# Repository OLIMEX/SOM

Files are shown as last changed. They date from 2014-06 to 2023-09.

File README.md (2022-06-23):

=System on Module=

This is the GitHub repository for Olimex System on Module (SOM) boards resources hardware and software.

OLIMEX System-on-Module (SOM) boards are powerful Linux-capable boards. They follow a low-cost modular design which allows rapid product development. Each of these boards has two parts - a main part which nests the processor, the memory and the power control unit; and a peripheral part which contains the USB ports, the video output and most of the connectors. SOM designs are targeted at customers who want to apply custom modifications and own solutions based on a specific processor without having to deal with multi layer PCBs with controlled impedance and BGA assembly. This makes it possible to create simpler boards (that might be manufactured by your local board manufacturer) containing only the peripherals you need with the dimensions and shape suitable for your specific solution.

Both the main part and the peripheral part of the SOM system have support in the official Android and Debian images distributed by Olimex and maintained by Olimex and the Linux community.

The peripheral part of the SOM design is considered Open Source HardWare (OSHW) and the customer has access to the board source files that we used to manufacture it. The part of the design that has the main microcontroller is considered proprietary design and design files would not be shared. The official Android and Debian images released for the SOM boards are open software. We usually try to provide step-by-step instructions on how we have compiled the images. These instructions might be found at the olimex wordpress page. 

If you are looking for the open source hardware design of the processors used, please, check the OLinuXino boards. OLinuXino board designs are fully open source hradware but harder to implement in own solutions and require more of a hardware experience to do so. Nevertheless OLinuXino boards are pretty good choice for evaluating the capabilities of the embedded processors.

At the moment Olimex deals with the following categories of SOM boards:

==Allwinner A13==

==Allwinner A20==

==Texas Instruments AM3352==

==Rockchip RK3188==

==Rockchip RK3328==

==STM STM32MP153==

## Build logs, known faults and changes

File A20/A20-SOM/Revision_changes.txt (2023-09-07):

Notable hardware changes in A20-SOM's design betwen revisions

Hardware revision C
========

1. Added resistor 10M parallel to the RTC crystal.
2. Changed the RTC crystal to SMT package.
3. Edited web-site white print to https://www.olimex.com
4. D5 positioned further away from UART0 conectora.
5. Major canges to the routing of DDR3 and NAND memory, similar to LIME2's. 
6. Instead of test pads, added new connector with the following signals:
	-> FMINL, FMINR, TVIN2, TVIN3, VMIC_OUT, AXP_BACKUP, AXP_RST, AXP_PWRON, UBOOT_SEL, VDD_RTC and GND;
7. Added new option - PC17 could be used for NWP signal if necessary, but R22 should be placed in this case!

Hardware revision D
========

1. Added matrix RM3 for the VGA signals.
2. Added pads for optional capacitors C178, C179, C180, C181 (NA by default).
3. VDD_RTC's label fixed from 3V3/30mA to 1V3/30mA.

Hardware revision E
========

1. Added AT24C16C EEPROM on TWI1 line. EEPROM address 0x50. Can cause problems with devices that use I2C1 since it blocks
addresses 0x50 to 0x57. The EEPROM comes loaded with production information, refer to this repo for more information:
https://github.com/OLIMEX/OLINUXINO/tree/master/SOFTWARE/A20/A20-eeprom-contents
2. Added eMMC option.
3. Added SPI flash option.
4. C162(220uF/6.3V/tant) changed to 4x47uF/6.3V/0805.
5. U2 and U3 changed from K4B4G1646D-BCK0 to MT41K256M16HA-125E(DDR3L-1600_11-11-11).
6. Added 5 x R22 resistors on ETX lines to reduce Ethernet noise.

Hardware revision E1
=========

1. C193 and L9 pads added for ETXCK and components not placed (NA).
2. Added option to make the board with T2 chip instead of A20.
3. Change RTC crystal with 1206 one.

Hardware revision E2
=========
Improved a lot of capacitors near the AXP209, so that they match the recommendations better:

1. C141 10uf/0603 --> 1uF/0603
2. C145 10uF/0603 --> 4.7uF/0603
3. C147 10uF/0603 --> 4.7uF/0603
4. C148 10uF/0603 --> 4.7uF/0603
5. C150 10uF/0603 --> 4.7uF/0603
6. C123 10uF/0603 --> 4.7uF/0603
7. C128 10uF/0603 --> 4.7uF/0603
8. C134 1uF/0603 --> 4.7uF/0603
9. C144 10uF/0603 --> 220nF/0603
10. 2.2uH/1.5A/DCR<0.1R/CD32 now 2.2uH/NR3015T2R2M/1.5A/3015
11. MCP120T475I-TT is now MCP121T475I-TT
12. Q32.768kHz/12.5pF/20ppm/4P/SMD8038 is now Q32.768kHz/12.5pF/2P/SMD1206

Hardware revision E3
=========
1. eMMC KLMAG2GEND-B031(FBGA153)(16G) changed with KLMAG1JETD-B041(FBGA153)(16G)
2. RAM changed to Samsung K4B4G1646D-BYK0 from Micron MT41K256M16HA-125E

Hardware revision E4
=======
1. Changed RAM used from Micron MT41K256M16HA-125E to Samsung K4B4G1646D-BYK0

Hardware revision F
=======

1. R86 and R72 connected to EFUSE_VDDQ.
2. Replaced U6 (MCP121T475I-TT) with U19(VDA4510CTA). U19(VDA4510CTA) was placed in parallel to U6(MCP121T475I-TT) and U6 was made NA. 
3. Added "CE" sign and "RoHS Compliant" text.
4. At some point 8GB eMMC(MTFC8GAKAJCN-4M IT) become unavable for purchase and the only repalcement avialable was 16GB industrial eMMC(KLMAG2GEUF-B04P). We decided to replace all 8GB eMMC with 16GB eMMC.

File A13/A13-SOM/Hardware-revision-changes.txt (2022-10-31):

Notable hardware changes for A13-SOM boards. 

In hardware revision Rev_E2
========
1. Changed RAM memory. New memory might have poor support in sunxi kernel u-boot; mainline u-boot should be used in case of issues.

In hardware revision Rev_F
========
1. C81 changed from 100uF/6.3V/tant/CT7343 to 2 x capacitors in parallel each 47uF/6.3V/20%/X5R/C0805;
2. L3 now 0R(board_mounted) resistor;
3. Package improvements of several components for better soldering;
4. Board size increased from 1300x2400mils to 1350x2400mils. Each side was increased with 25mils. This was done due to complaints about the reliability of the plastic headers. They should be more reliable now.

In hardware revision Rev_G
========
1. The packages of most resistor matrices improved;
2. C67 and C76 changed from 22pF to 33pF;
3. L1 changed from CL470nH/0805/1.76R/250mA to FB0805/600R/2A;
4. In A13-SOM256: R7 and R9 changed from 330 Ohm to 240 Ohm

In hardware revision Rev_G1
=========
1. RAM memory changed to K4B4G1646D-BYK0.
2. SY8009 changed with SY8089. 
3. 2.2uH (L2 and L4) now 2.2uH/NR3015T2R2M/1.5A/3015.
4. Changed R13 from 2k/1%/0603 to 2.2k/1%/0603, this is done to increase
the voltage on the processor to around 1.45V.

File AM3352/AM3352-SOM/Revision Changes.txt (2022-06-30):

AM3352-SOM notable hardawre revision changes

Hardware revision C1
===
1. R46 value changed from 10k to 1k.

Hardware revision D
===
1. NAND_RPR jumper was added to avoid the problem with booting when the NAND is broken;
2. All SY8009AAAC changed to SY8089AAAC.

Hardware revision E
===
1. Q1 changed from 32768Hz/6pF/4P to Q32.768kHz/12.5pF/2P/SMD1206;
2. C89 and C91 changed from 10pF to 22pF;
3. The drills under C100 were moved a little bit away from the pads. So L3 was moved 5mils to the right;
4. NAND_RPR jumper replaced with the R66(NA(10k)) resistor. In addition, R65(NA(10k)) and R67-R69(NA(10k)) added to support different boot orders, as written in the schematic, if required.
5. L4, L5, L7 and L8 changed from 2.2uH/1.5A/DCR<0.1R/CD32 to 2.2uH/1.5A/DCR=72mR/20%/3.00x3.00x1.50mm/CD32(NR3015T2R2M);
6. L6 changed from CL470nH/0805/1.76R/250mA to FB0805/600R/2A;
7. D1's value changed from 1N4148 to 1N4148W(SOD-123);
8. The board enlarged with 10mils around for to avoid having drills and wires close to the board's edge;
9. When there is no NAND there is no need to populate c106 and r28.

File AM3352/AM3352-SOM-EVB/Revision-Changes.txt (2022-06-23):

Hardware revision changes AM3352-SOM-EVB:

In revision E
====
1. Q1's package changed from 32768Hz/6pF/4P to Q32.768kHz/12.5pF/2P/SMD1206;
2. C89 and C91 values changed from 10pF to 22pF;
3. The drills under C100 were moved a little bit away from the pads. For this purpose L3 was moved 5mils to the right;
4. NAND_RPR jumper replaced by the R66(NA(10k))resistor. In addition, R65(NA(10k))and R67-R69(NA(10k)) added to support different boot order, as written in the schematic, if required.
5. L4,L5,L7 and L8 changed from 2.2uH/1.5A/DCR<0.1R/CD32 to 2.2uH/1.5A/DCR=72mR/20%/3.00x3.00x1.50mm/CD32(NR3015T2R2M);
6. L6 changed from CL470nH/0805/1.76R/250mA to FB0805/600R/2A;
7. D1's value changed from 1N4148 to 1N4148W(SOD-123);
8. The board enlarged with 10 mils around to avoid having drills and wires close to the board's edge;
9. When there is no NAND, we don't populate c106 and r28.

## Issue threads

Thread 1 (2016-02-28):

PCB design files for A13-SOM

AlexDaniel, 2016-02-28:
I can only see schematics here: https://github.com/OLIMEX/SOM/tree/master/A13/A13-SOM
What about .brd files?

DanKoloff, 2016-02-29:
Hey there,

The SOM boards designed and manufactured by Olimex LTD are not open-source hardware. If you look at the web-pages of A13-SOM, A20-SOM, RK3188-SOM, etc/ you would notice that they don't have the OSHW logo. Only the reference shields for these boards are open-souce hardware (like A13-SOM-WIFI, A20-SOM-EVB, etc).

This is described in the documentation. More information can also be found here: [https://www.olimex.com/Products/SOM/](https://www.olimex.com/Products/SOM/)

If you are looking for OSHW design with Allwinner A13 - take a look at OLinuXino and LIME boards. For example, A13-OLinuXino and A13-OLinuXino-MICRO are OSWH boards.

Best regards,
Lub/OLIMEX

Closed 2016-02-29.

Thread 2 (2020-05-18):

datasheet of RK3188

iysheng, 2020-05-18:
Hi，thanks for your work，and i want design a board based on your RK3188-SOM,I can get your schematics, could you provide the datasheet or usermanual of RK3188,i google some thing but no get the right doc.

TsvetanUsunov, 2020-05-18:
you didn't search hard enough https://github.com/OLIMEX/OLINUXINO/tree/master/DOCUMENTS/RK3188-PDFs

iysheng, 2020-05-18:
>
>
> you didn't search hard enough https://github.com/OLIMEX/OLINUXINO/tree/master/DOCUMENTS/RK3188-PDFs

e, thanks for your reply,

Closed 2020-05-18.

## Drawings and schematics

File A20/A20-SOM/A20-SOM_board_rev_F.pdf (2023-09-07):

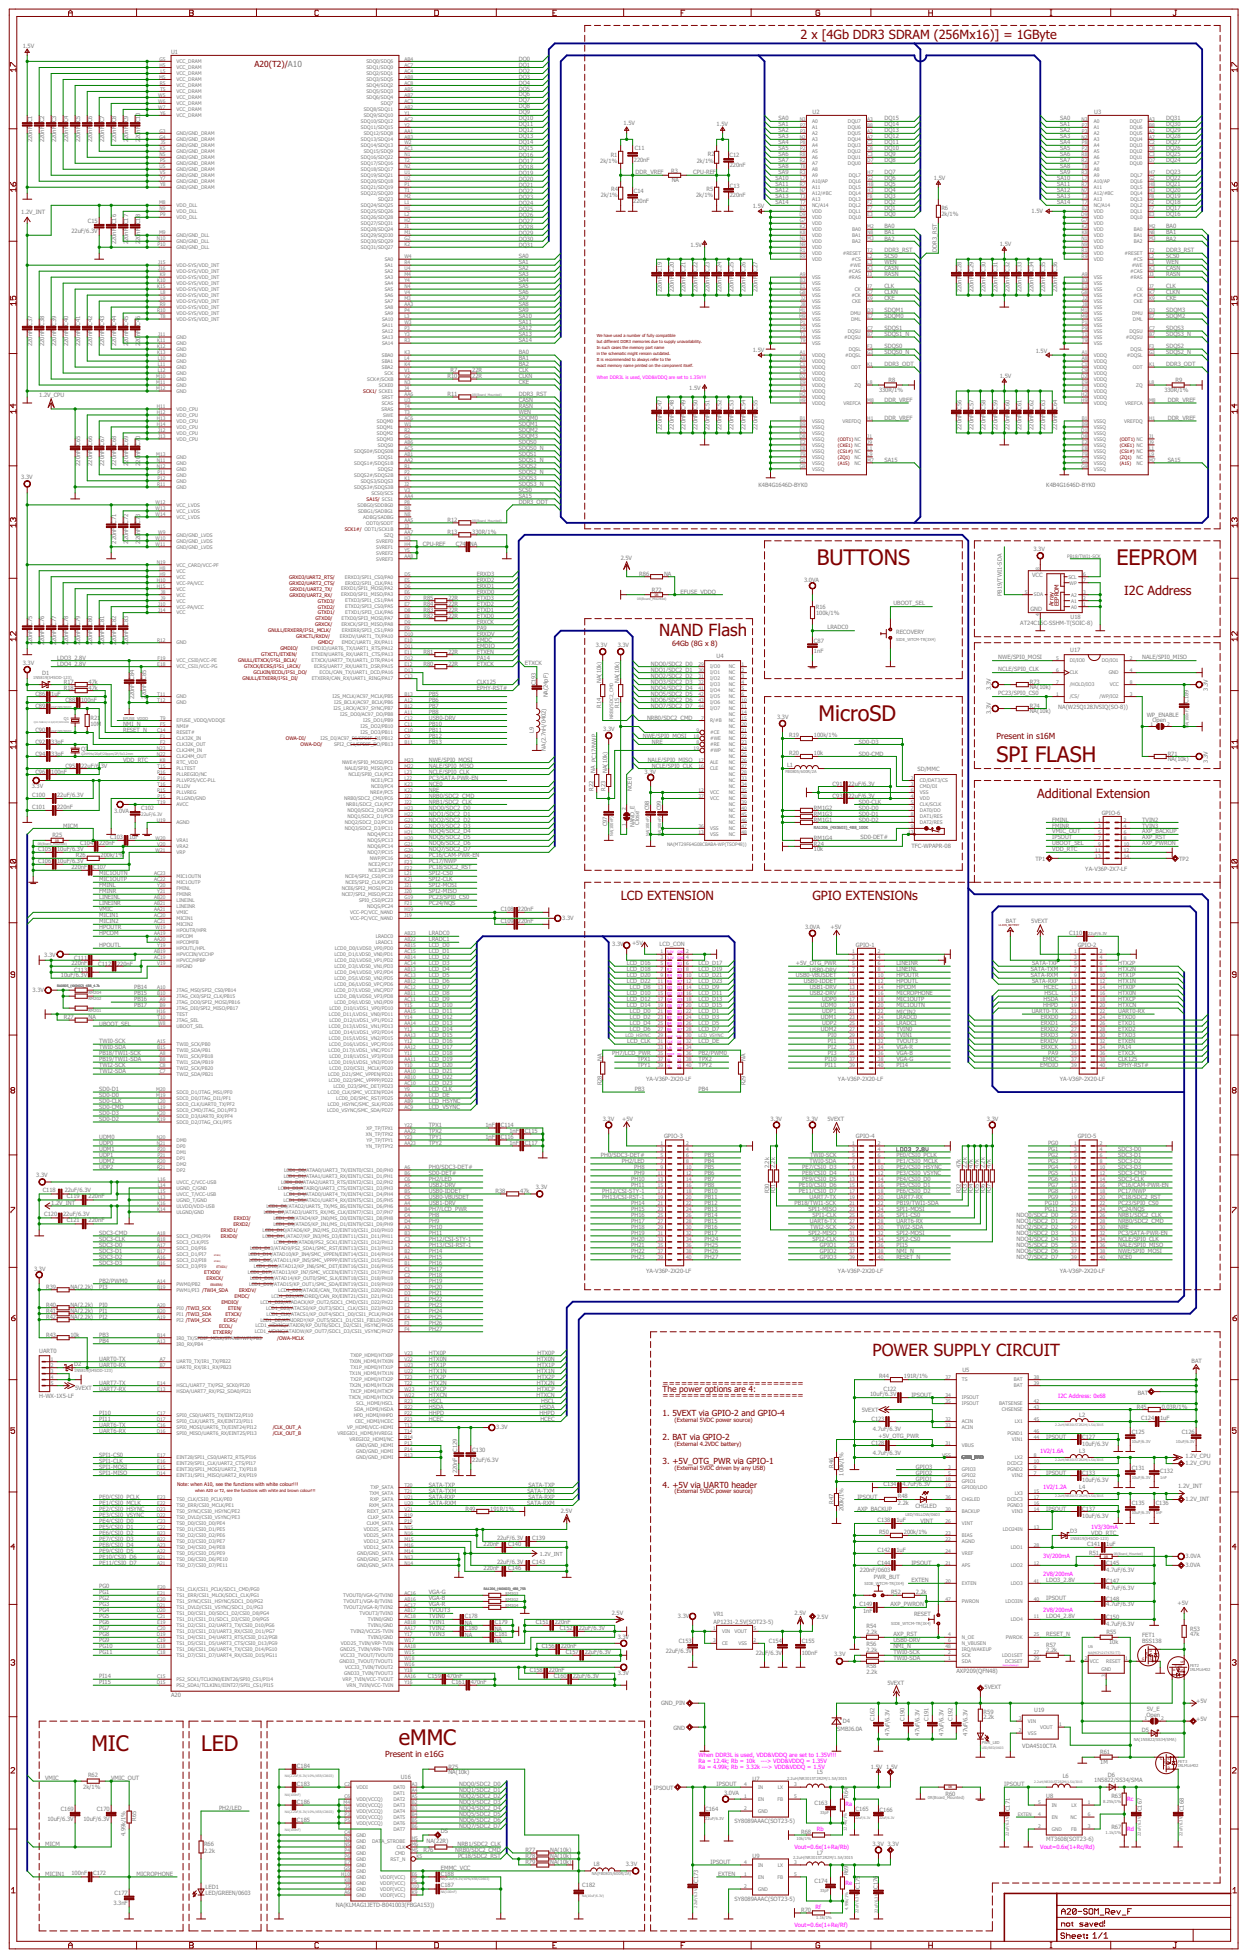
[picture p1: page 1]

We have used a number of fully compatible but different DDR3 memories due to supply unavailability. In such cases the memory part name

in the schematic might remain outdated. It is recommended to always refer to the

exact memory name printed on the component itself.

When DDR3L is used, VDD&VDDQ are set to 1.35V!!!

GRXD3/UART2_RTS/ GRXD2/UART2_CTS/ GRXD1/UART2_TX/ GRXD0/UART2_RX/ GTXD3/ GTXD2/ GTXD1/ GTXD0/ GRXCK/ GNULL/ERXERR/I²S1_MCLK/ GRXCTL/RXDV/ GMDC/ GMDIO/ GTXCTL/ETXEN/ GNULL/ETXCK/I²S1_BCLK/ GTXCK/ECRS/I²S1_LRCK/ GCLKIN/ECOL/I²S1_DO/ GNULL/ETXERR/I²S1_DI/

OWA-DI/ OWA-DO/

The power options are 4: 1. 5VEXT via GPIO-2 and GPIO-4

3. +5V_OTG_PWR via GPIO-1
(External 5VDC driven by any USB)

Note: when A10, see the functions with white colour!!! when A20 or T2, see the functions with white and brown colour!!!

When DDR3L is used, VDD&VDDQ are set to 1.35V!!! Ra = 12.4k; Rb = 10k ---> VDD&VDDQ = 1.35V Ra = 4.99k; Rb = 3.32k ---> VDD&VDDQ = 1.5V

RcRd Vout=0.6x(1+Rc/Rd) Re Rf Vout=0.6x(1+Re/Rf)

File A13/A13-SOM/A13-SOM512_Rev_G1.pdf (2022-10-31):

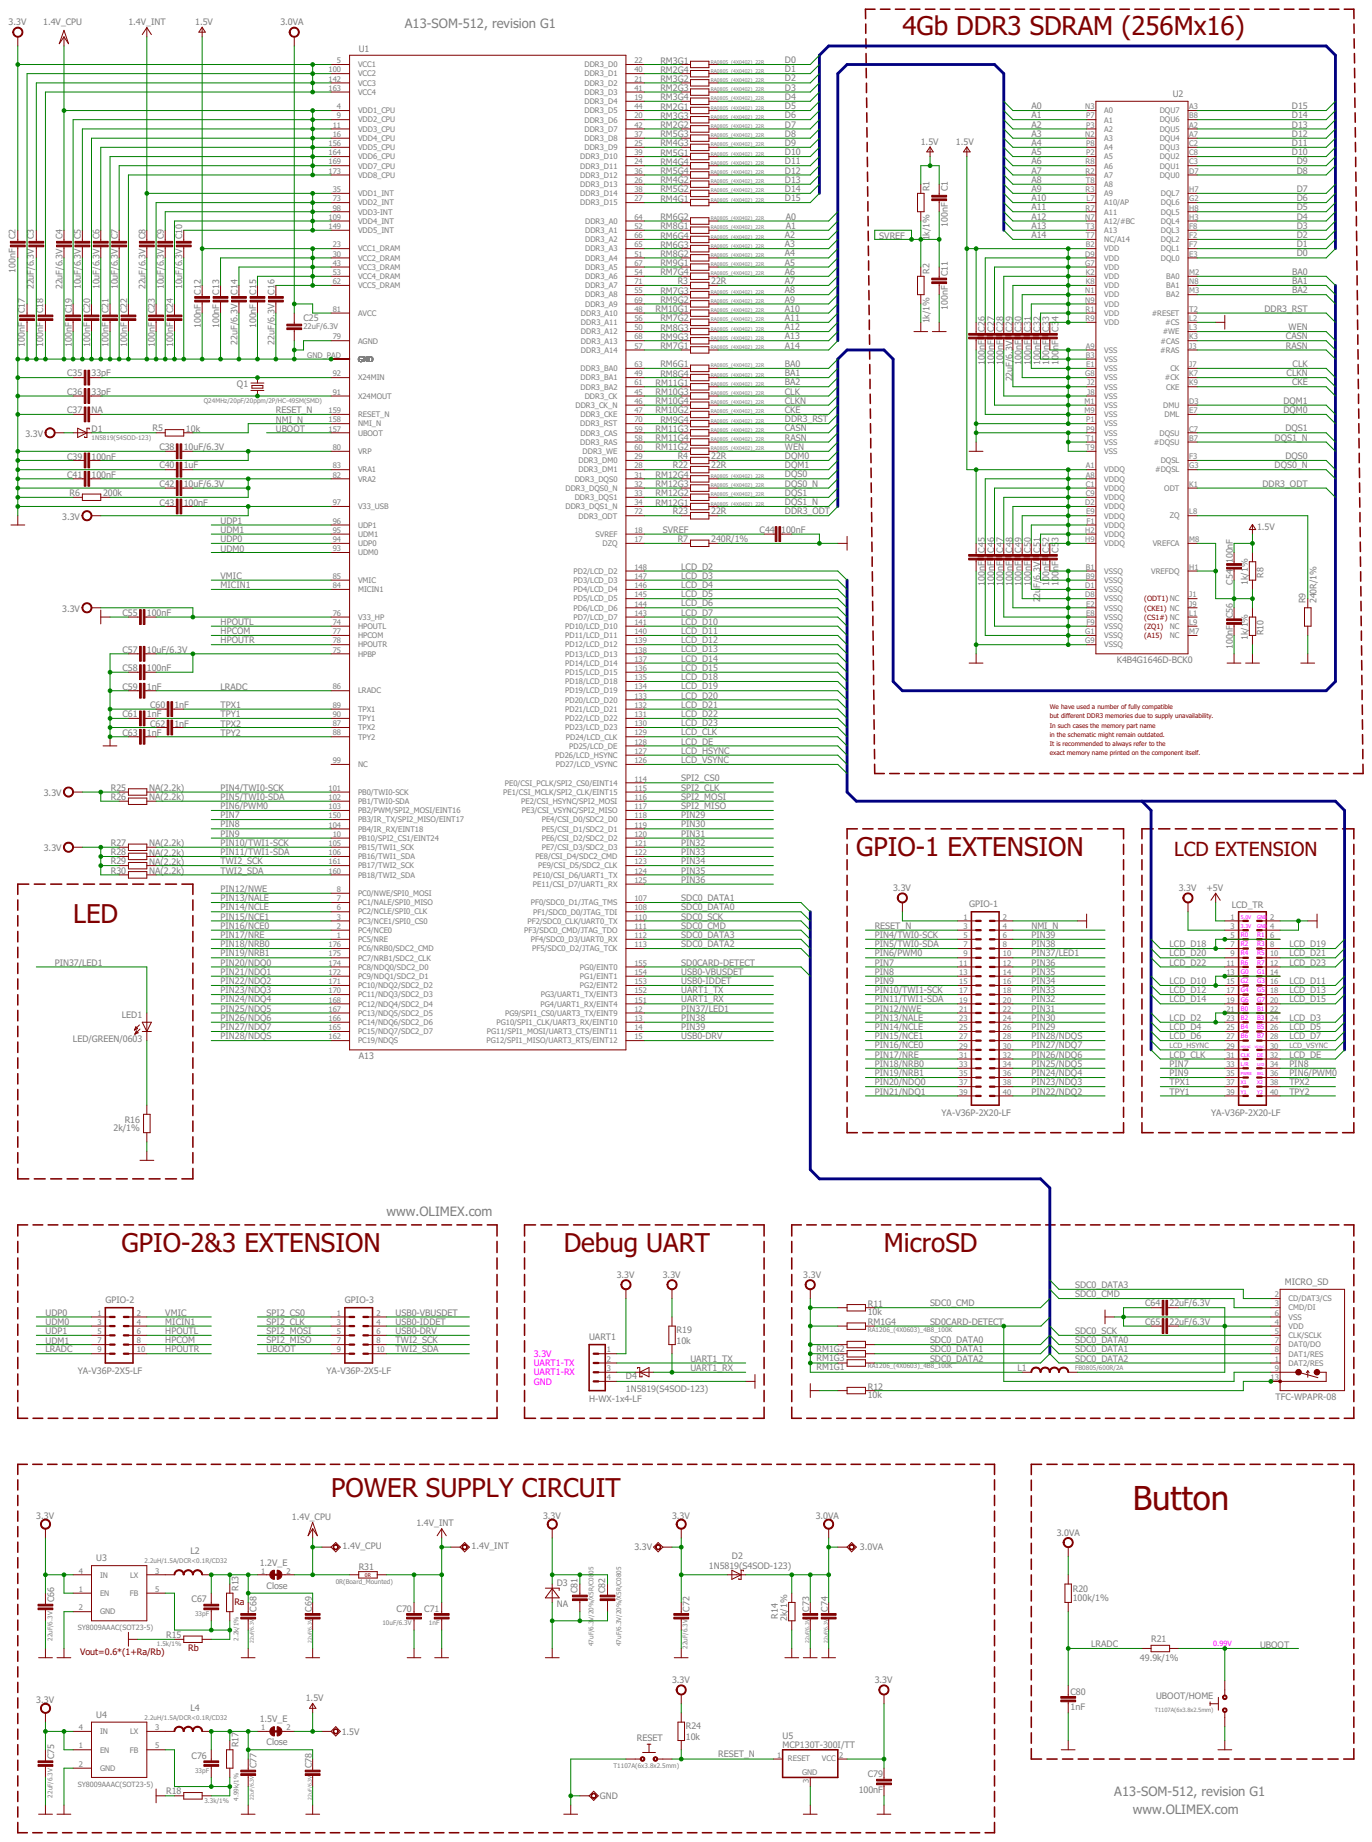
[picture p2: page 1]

142 | RM2G1 RM2G2 RM2G3 RM2G4 RM3G1 RM3G2 RM3G3 RM3G4 40 DDR3_D3
100 | 21 DDR3_D0

4 | 20 DDR3_D2 41 DDR3_D7
163

30
81 | RM9G1 RM9G2 RM9G3
62 | 54 DDR3_A8 71 R3

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

in the schematic might remain outdated. It is recommended to always refer to the

exact memory name printed on the component itself.

Ra Rb Vout=0.6*(1+Ra/Rb)

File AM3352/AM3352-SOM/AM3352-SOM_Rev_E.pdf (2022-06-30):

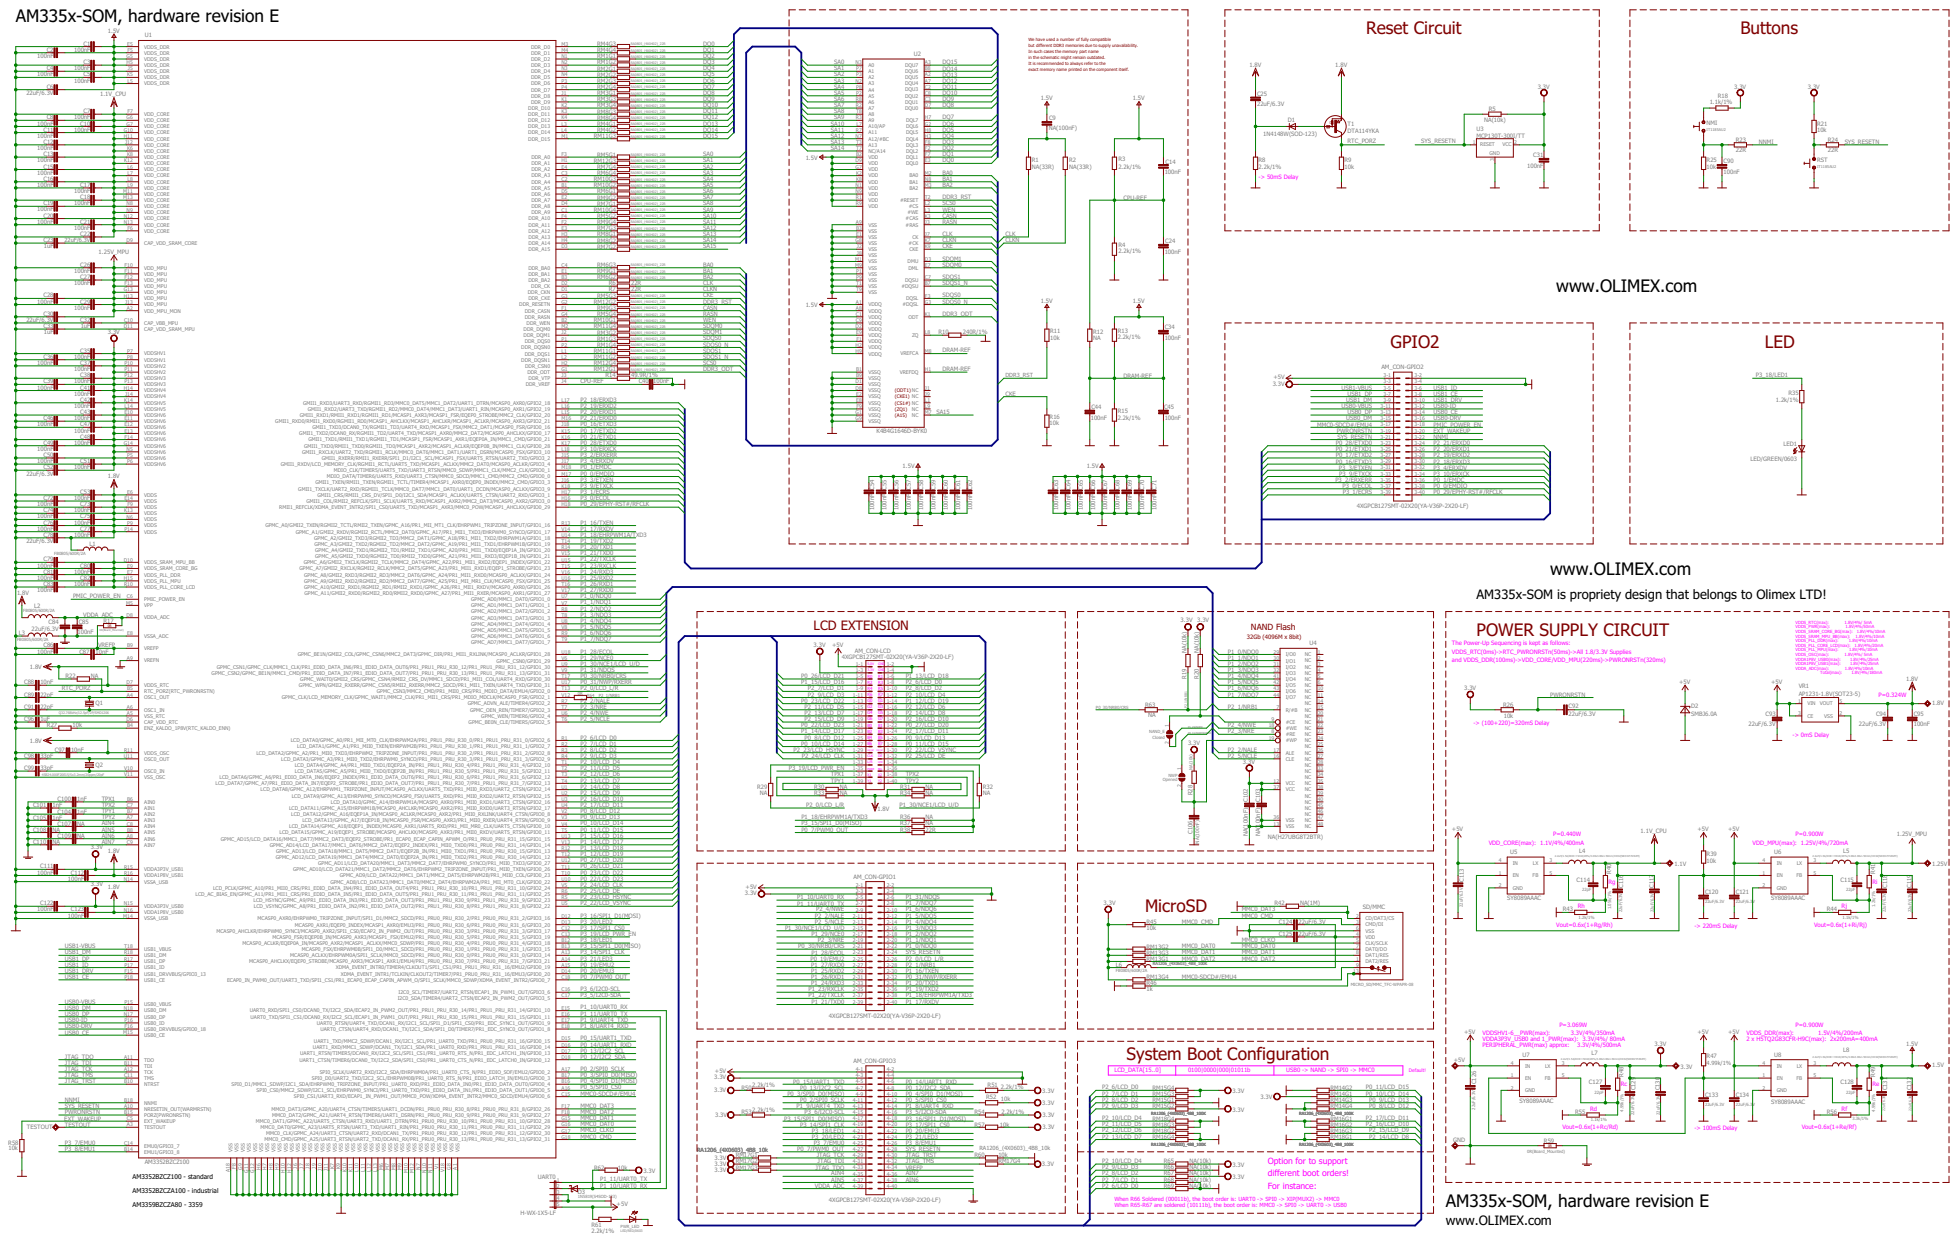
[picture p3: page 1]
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

in the schematic might remain outdated. It is recommended to always refer to the

exact memory name printed on the component itself.

DRAM-REF DRAM-REF DRAM-REF

AM335x-SOM is propriety design that belongs to Olimex LTD!

The Power-Up Sequencing is kept as follows: VDDS_RTC(0ms)->RTC_PWRONRSTn(50ms)->All 1.8/3.3V Supplies and VDDS_DDR(100ms)->VDD_CORE/VDD_MPU(220ms)->PWRONRSTn(320ms)

Rg Rh Vout=0.6x(1+Rg/Rh)

Ri Rj Vout=0.6x(1+Ri/Rj)

Rc Rd Vout=0.6x(1+Rc/Rd)

Re Rf Vout=0.6x(1+Re/Rf)

When R66 Soldered (00011b), the boot order is: UART0 -> SPI0 -> XIP(MUX2) -> MMC0 When R65-R67 are soldered (10111b), the boot order is: MMC0 -> SPI0 -> UART0 -> USB0

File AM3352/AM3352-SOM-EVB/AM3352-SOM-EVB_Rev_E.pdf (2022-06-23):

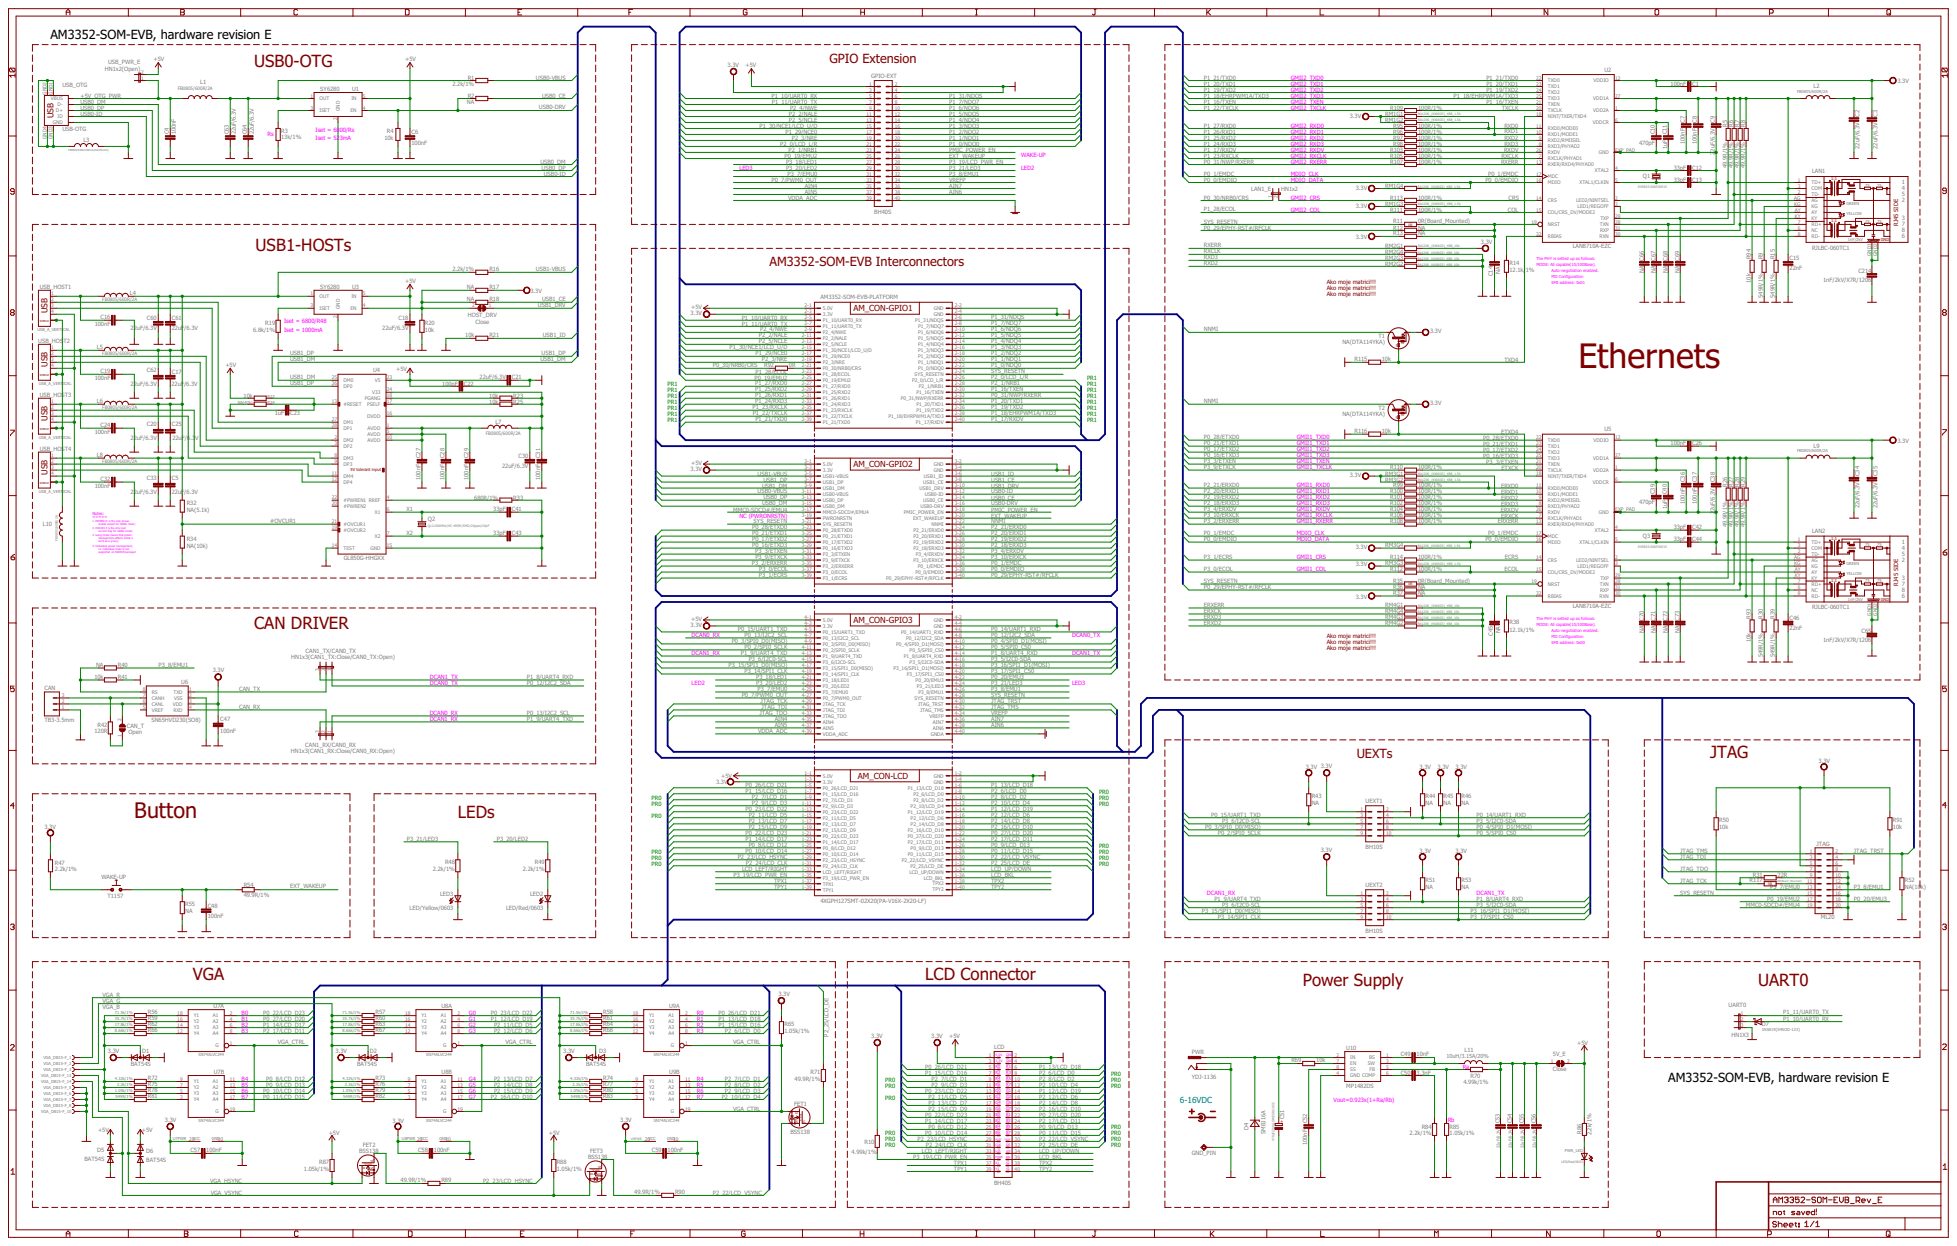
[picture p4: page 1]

AM3352-SOM-EVB, hardware revision E

The PHY is setted up as follows: MODE: All capable(10/100Base). Auto-negotiation enabled. MII Configuration

Ako moje matrici!!! Ako moje matrici!!! Ako moje matrici!!!

enable output for GANG mode; 1. PWREN1# is the only power- Notes:

current flag for GANG mode; 2. OVCUR1# is the only over ports as a group; 3. Gang mode means that power 4. Individual power management,

i.e. individual mode is not supported on SSOP28 package!

Rb Vout=0.923x(1+Ra/Rb)

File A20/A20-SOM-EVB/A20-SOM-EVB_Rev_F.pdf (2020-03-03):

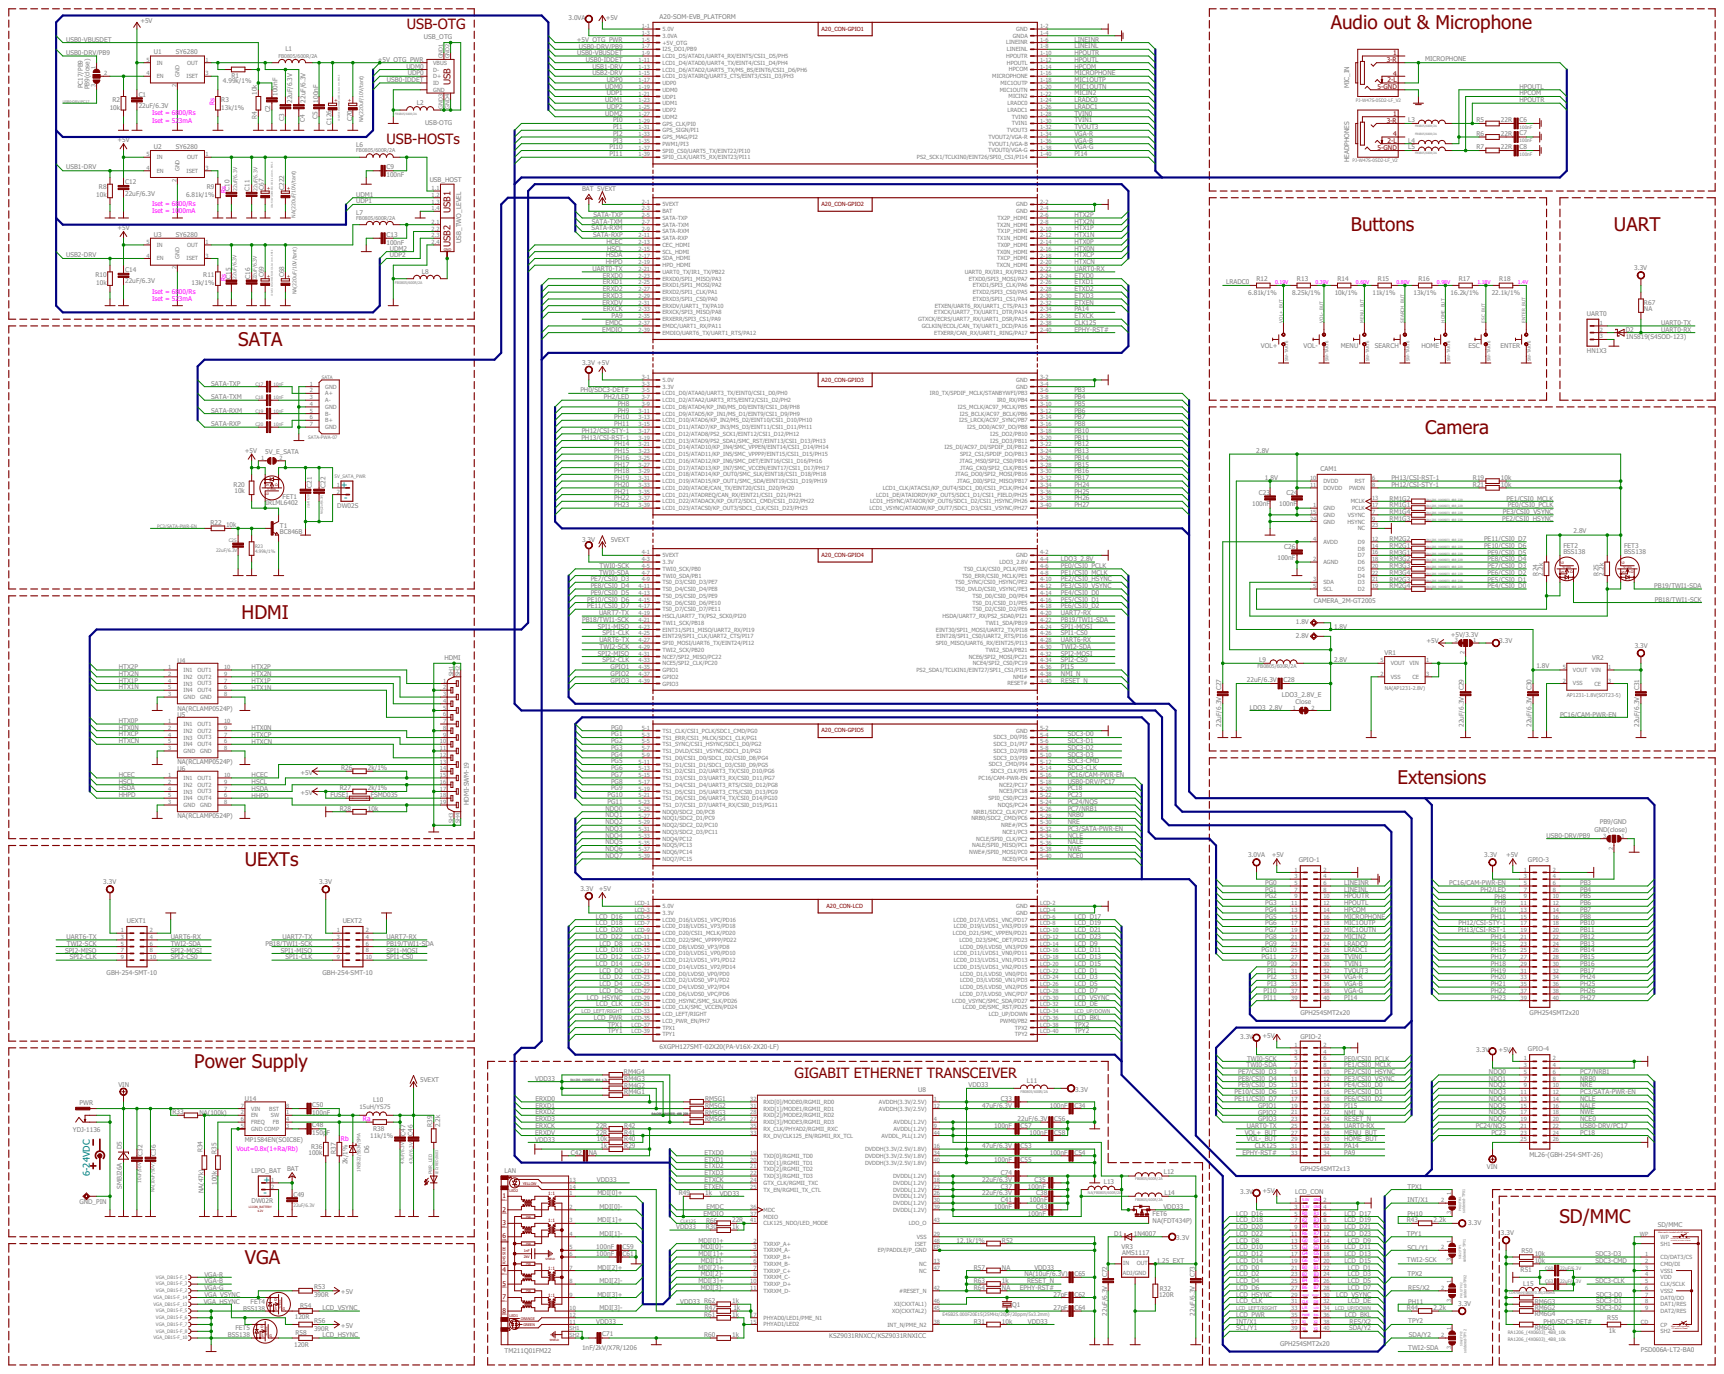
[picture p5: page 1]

NA(220uF/10V/tant)

soldered-TPX2 soldered-TPY2 soldered-TPY1 soldered-TPX1

When card is inserted with WP status: Locked, WP switch is Opened Unlocked, WP switch is Closed

When card is inserted, CP switch is Closed

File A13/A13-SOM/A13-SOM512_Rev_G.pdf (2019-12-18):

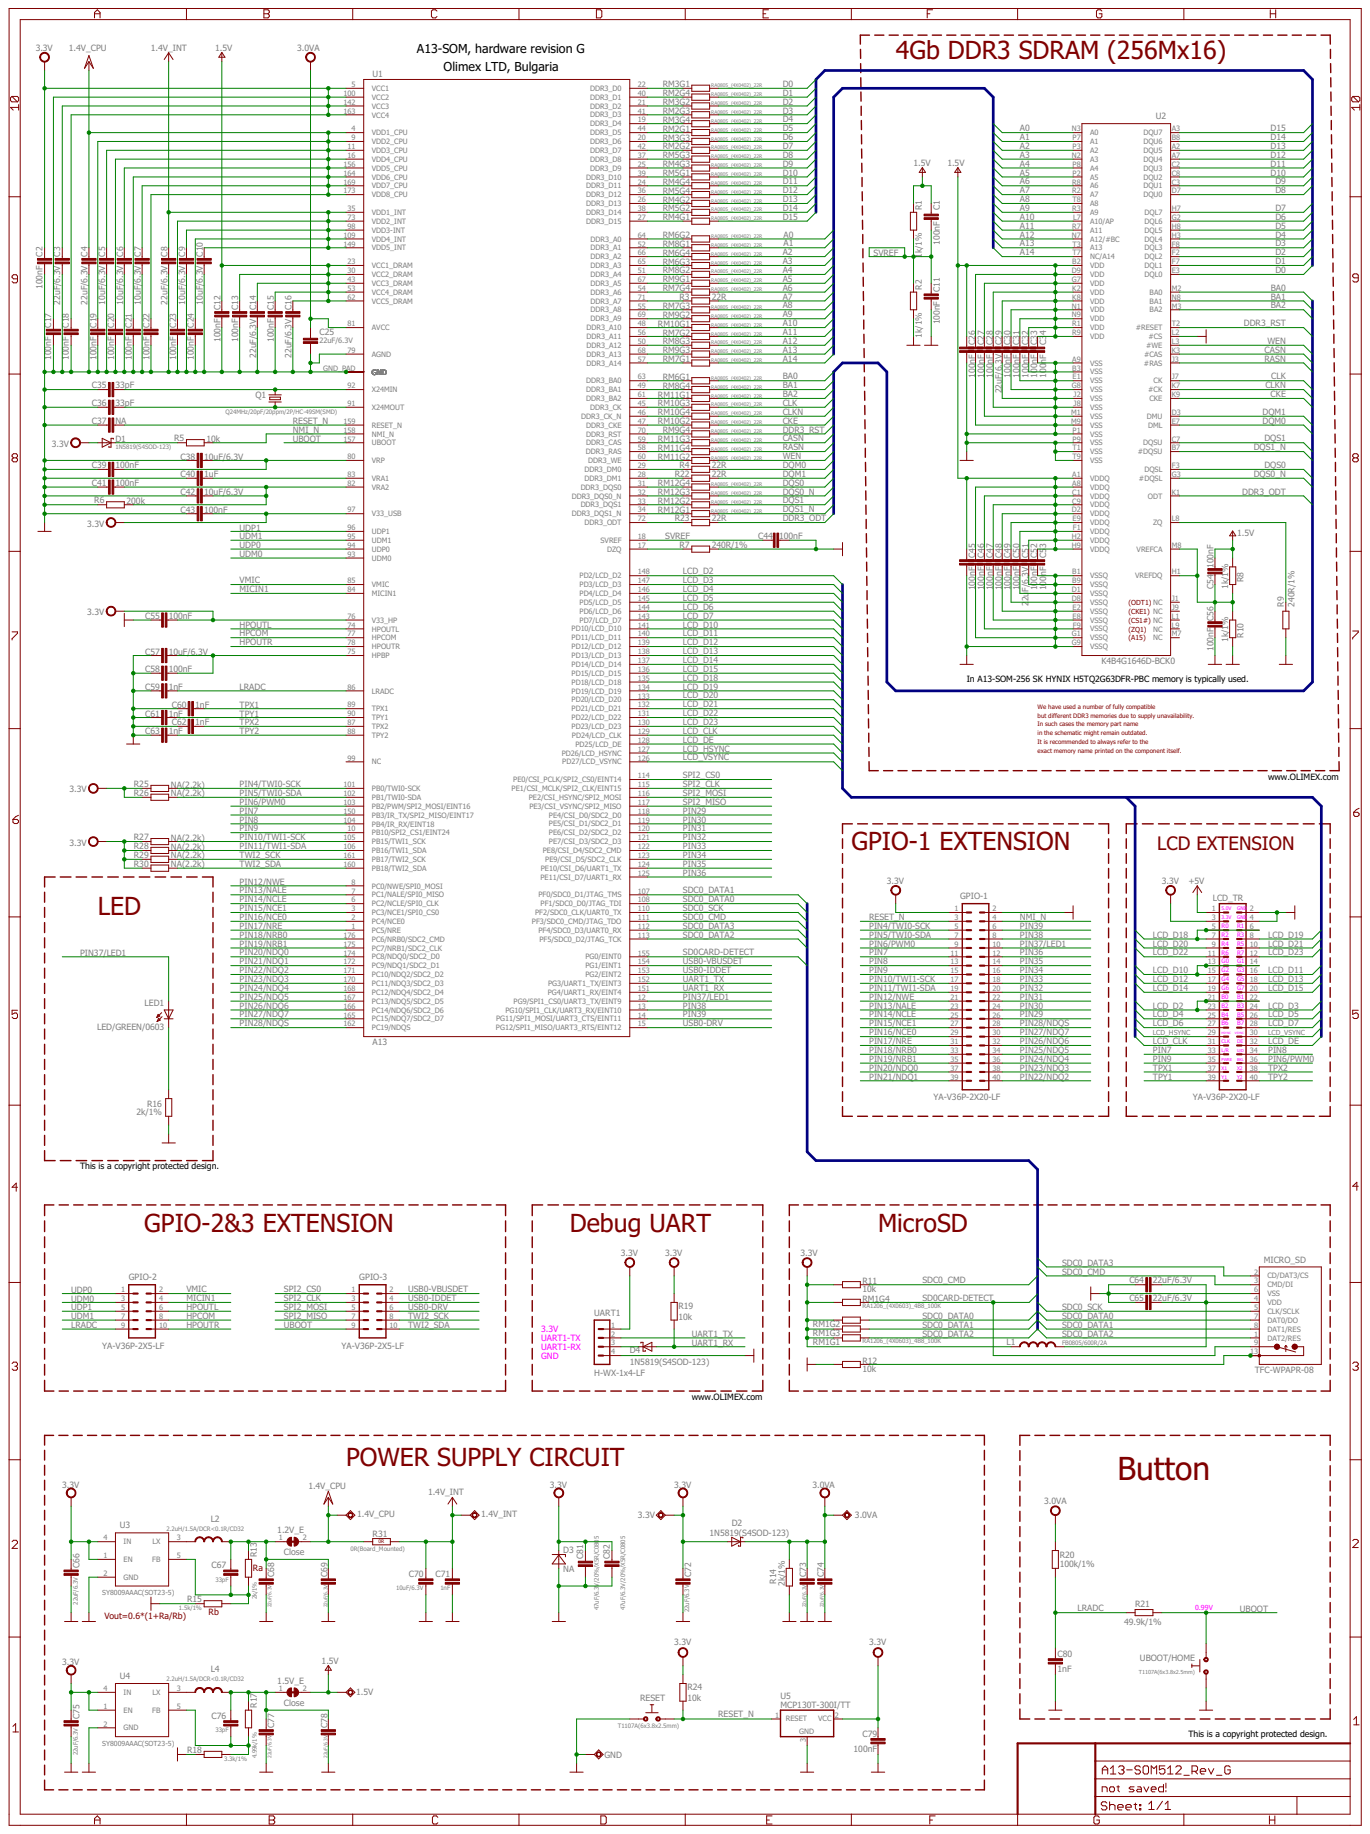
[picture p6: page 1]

A13-SOM, hardware revision G Olimex LTD, Bulgaria

142 | RM2G1 RM2G2 RM2G3 RM2G4 RM3G1 RM3G2 RM3G3 RM3G4 40 DDR3_D3
100 | 21 DDR3_D0

4 | 20 DDR3_D2 41 DDR3_D7
163

In A13-SOM-256 SK HYNIX H5TQ2G63DFR-PBC memory is typically used.

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

in the schematic might remain outdated. It is recommended to always refer to the

exact memory name printed on the component itself.

This is a copyright protected design.

Ra Rb Vout=0.6*(1+Ra/Rb)

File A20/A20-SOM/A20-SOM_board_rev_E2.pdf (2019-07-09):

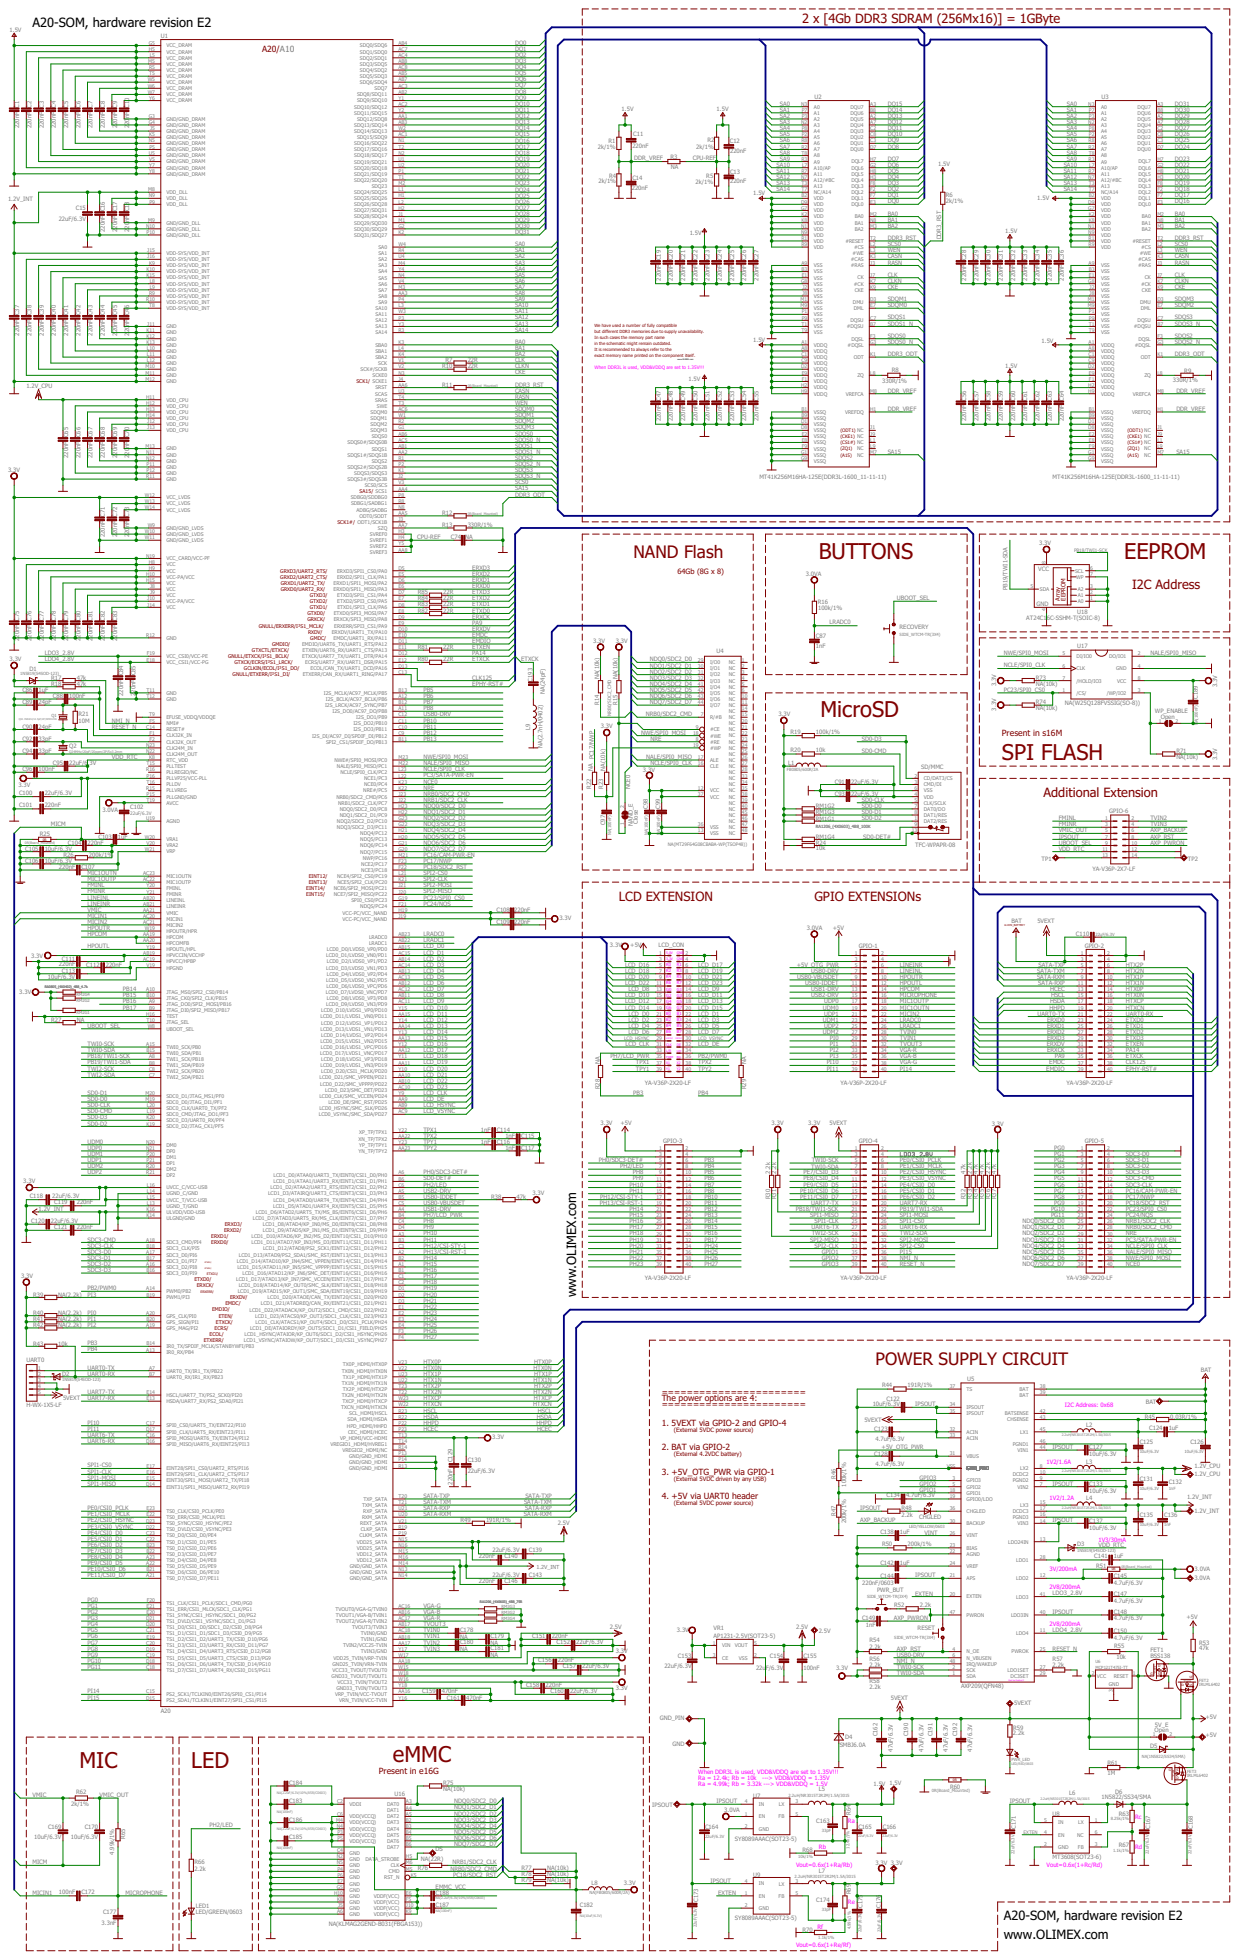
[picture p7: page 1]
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

in the schematic might remain outdated. It is recommended to always refer to the

exact memory name printed on the component itself.

When DDR3L is used, VDD&VDDQ are set to 1.35V!!!

R11 | VCC_LVDS W12 VCC_LVDS W13 VCC_LVDS W14 | J2

GRXD3/UART2_RTS/ GRXD2/UART2_CTS/ GRXD1/UART2_TX/ GRXD0/UART2_RX/ GTXD3/ GTXD2/ GTXD1/ GTXD0/ GRXCK/ GNULL/ERXERR/I²S1_MCLK/ RXDV/ GMDC/ GMDIO/ GTXCTL/ETXCK/ GNULL/ETXCK/I²S1_BCLK/ GTXCK/ECRS/I²S1_LRCK/ GCLKIN/ECOL/I²S1_DO/ GNULL/ETXERR/I²S1_DI/

VRA1 W20 VRP W21 VRA2 V20 FMINL Y20 LINEINL AB20 MICIN1 AC20 MICIN2 AC21 HPOUTR/HPR W19 HPOUTL/HPL Y19 HPVCCIN/VCCHP AB19 HPVCC/HPBP AC19 | J22 NRB0/SDC2_CMD/PC6

The power options are 4: 1. 5VEXT via GPIO-2 and GPIO-4

3. +5V_OTG_PWR via GPIO-1
(External 5VDC driven by any USB)

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

Rc Rd Vout=0.6x(1+Rc/Rd) Re Rf Vout=0.6x(1+Re/Rf)

A20-SOM, hardware revision E2 www.OLIMEX.com

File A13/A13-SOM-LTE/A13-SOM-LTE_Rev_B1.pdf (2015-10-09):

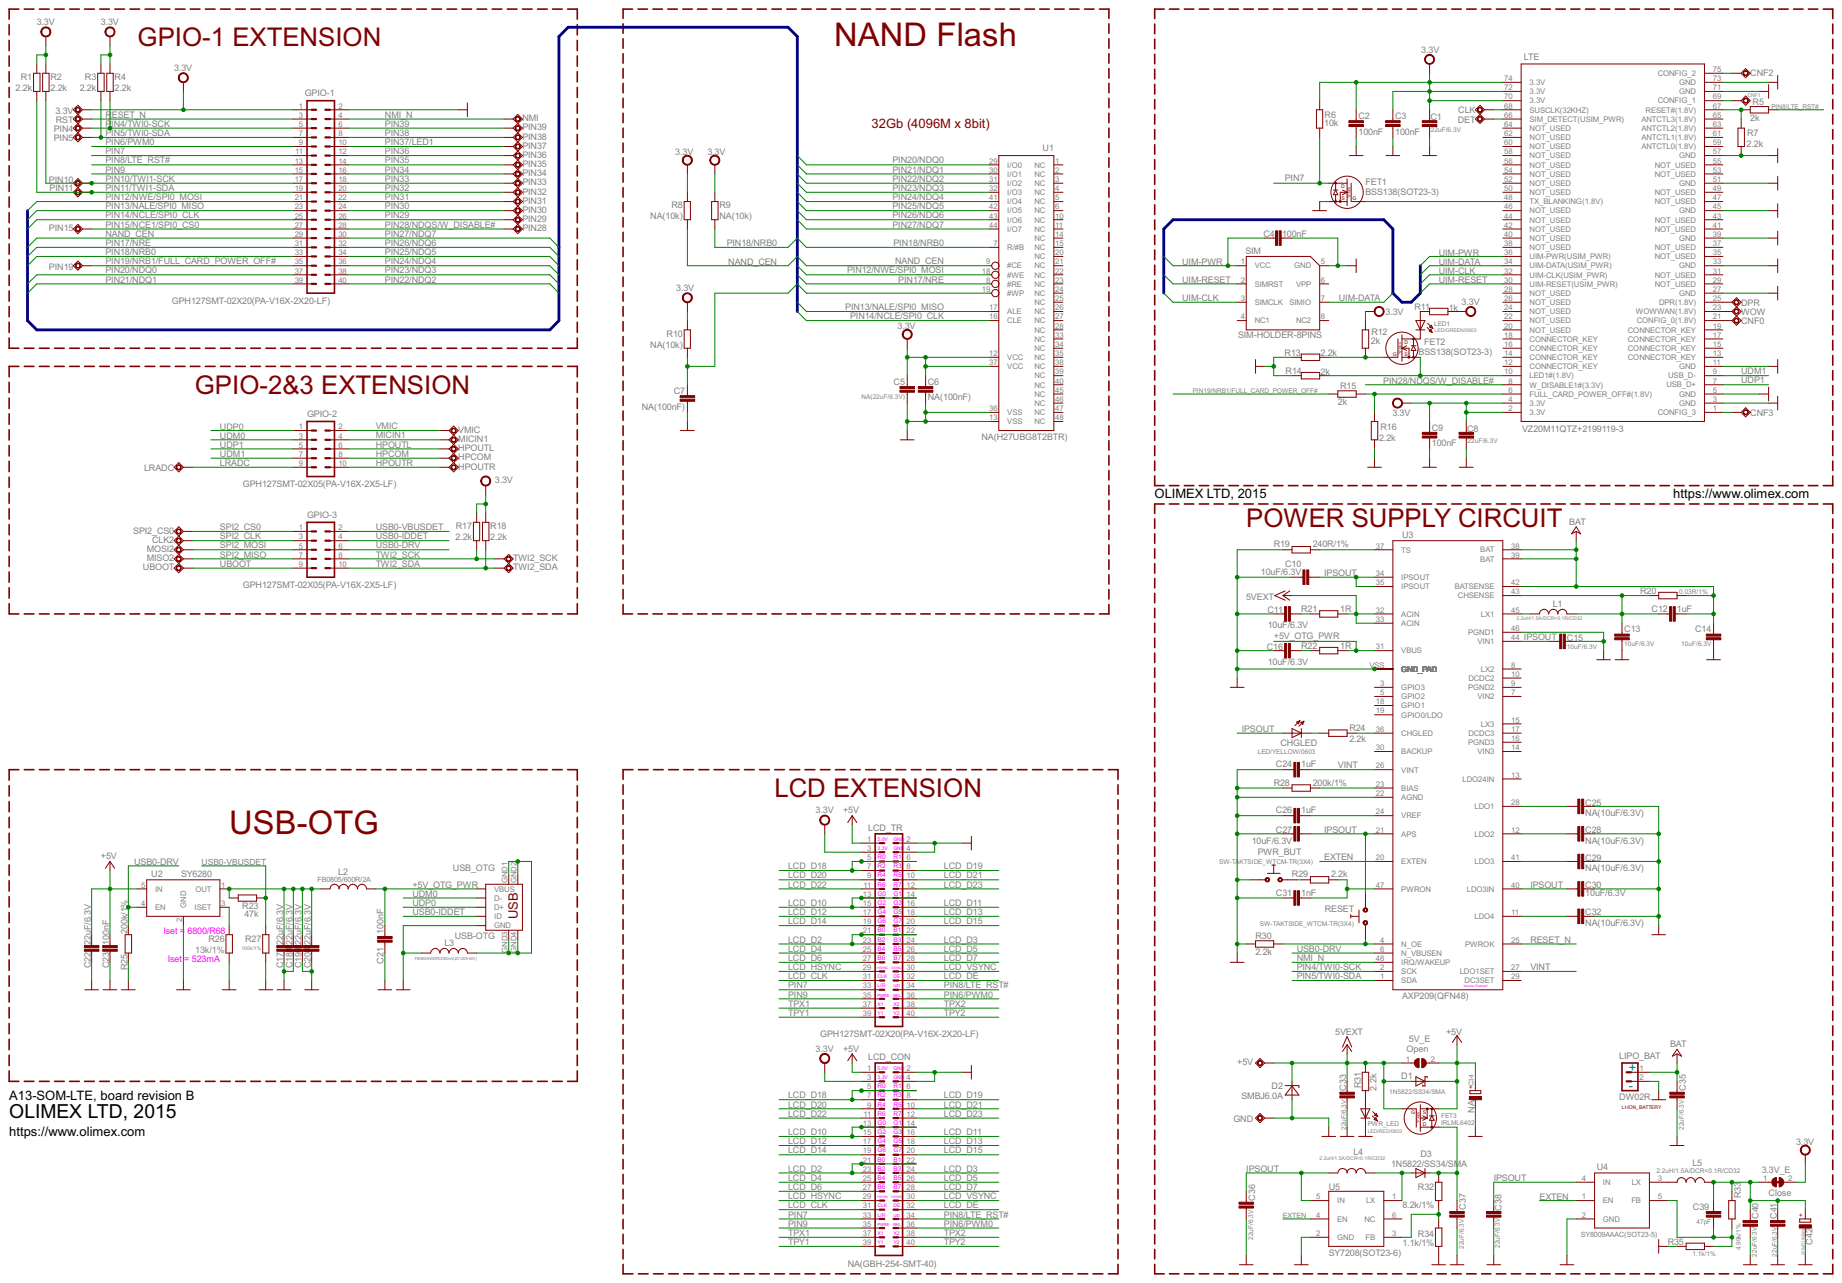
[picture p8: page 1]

PIN4/TWI0-SCK | 5 | 6 PIN39 PIN38

https://www.olimex.com

A13-SOM-LTE, board revision B OLIMEX LTD, 2015

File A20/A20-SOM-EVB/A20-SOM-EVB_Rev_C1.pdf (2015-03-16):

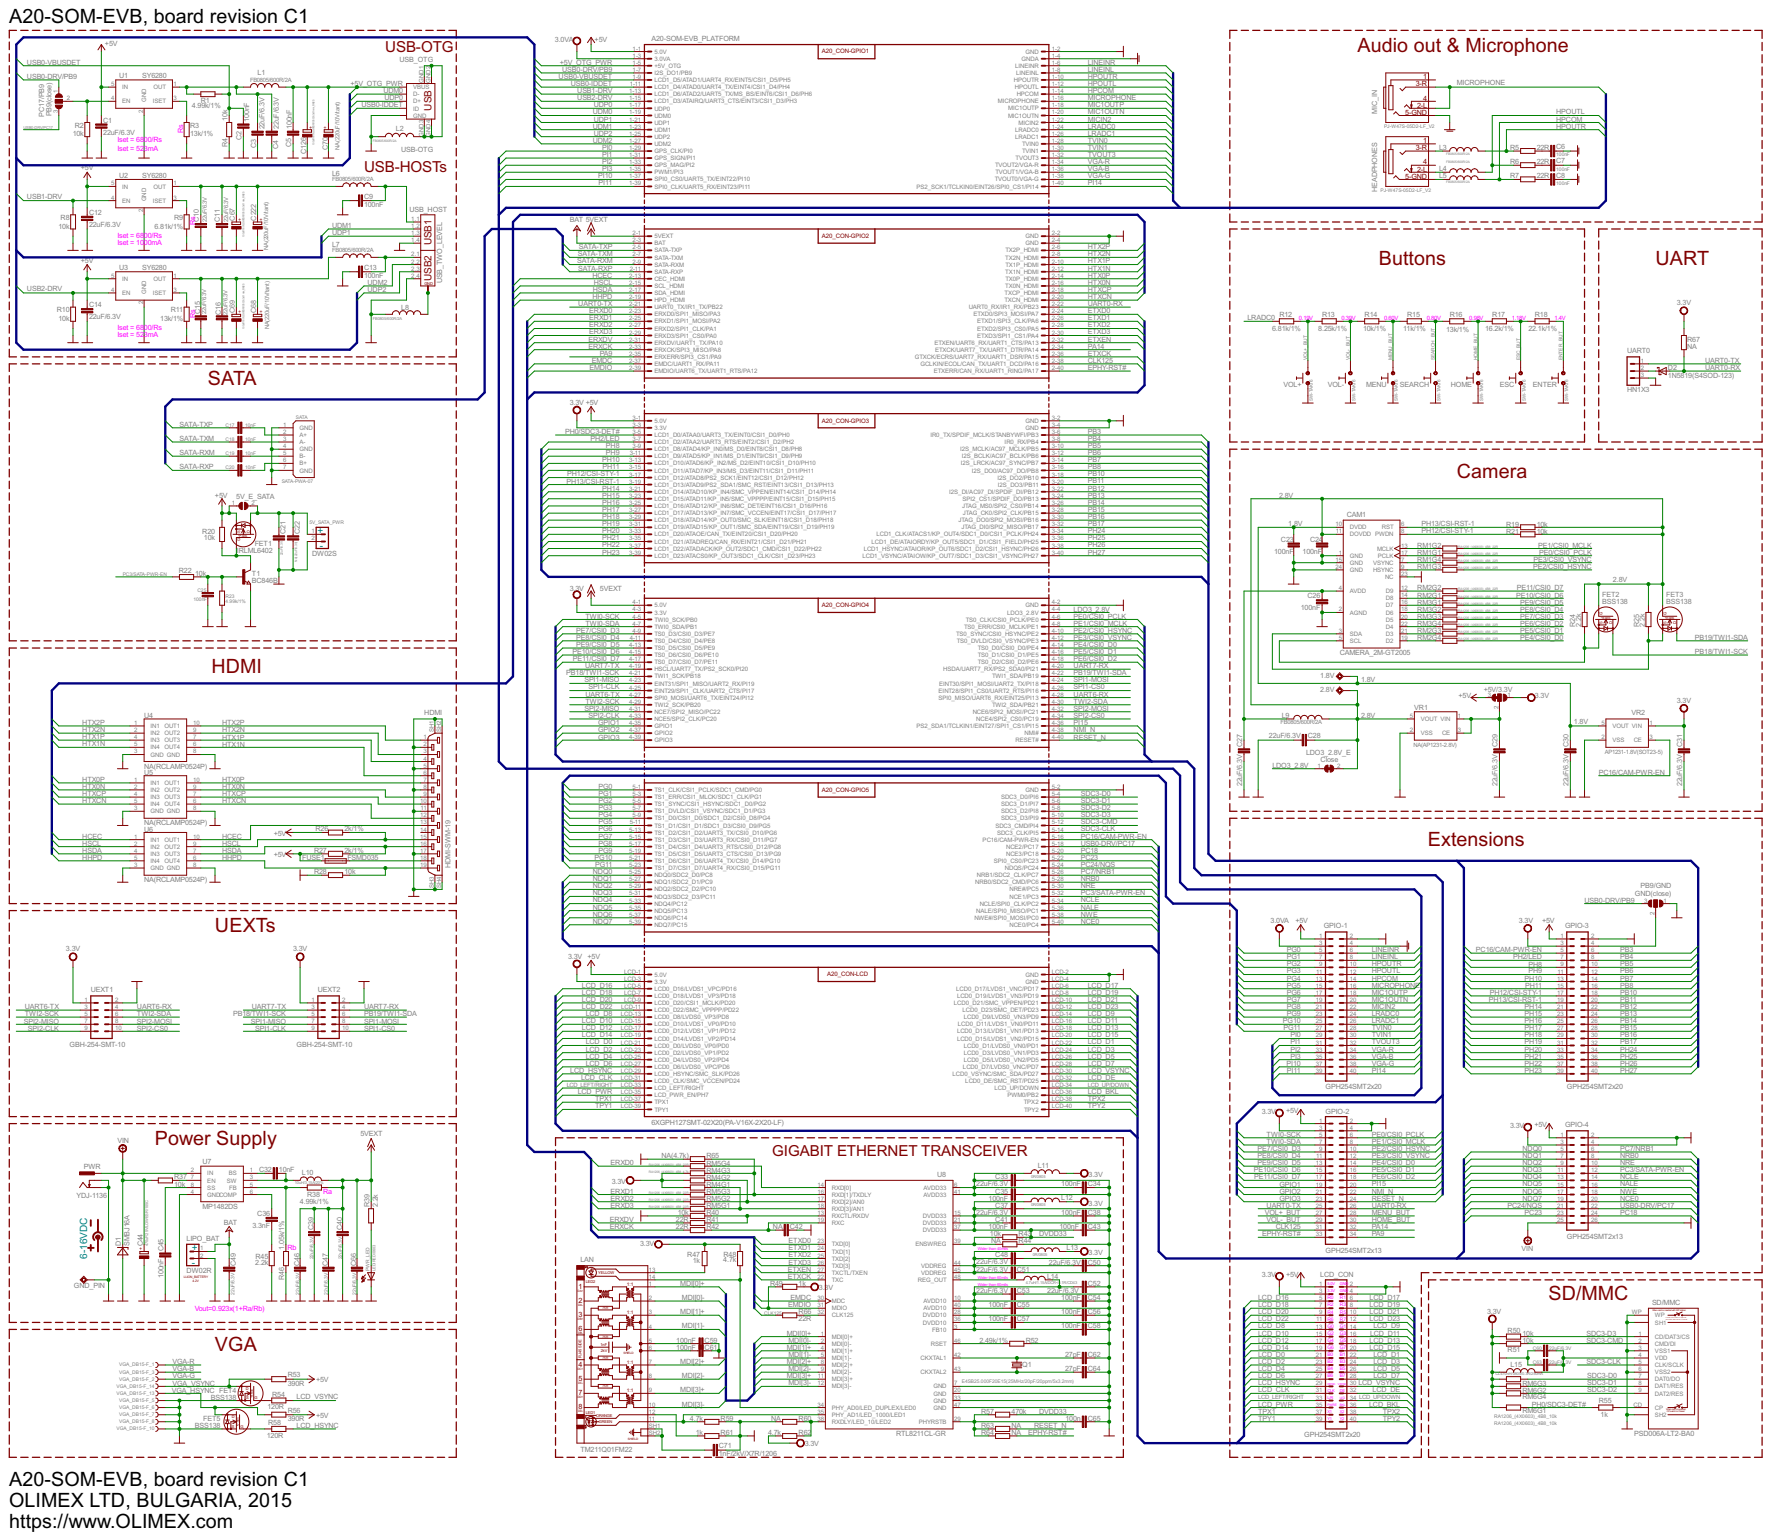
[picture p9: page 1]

A20-SOM-EVB, board revision C1

NA(220uF/10V/tant)

Wider than 40mils Wider than 60mils Wider than 60mils

When card is inserted with WP status: Loc ked, W P switc h is Opened Unloc ked, W P switc h is Clos ed

When card is inserted, CP switch is Closed

OLIMEX LTD, BULGARIA, 2015
https://www.OLIMEX.com

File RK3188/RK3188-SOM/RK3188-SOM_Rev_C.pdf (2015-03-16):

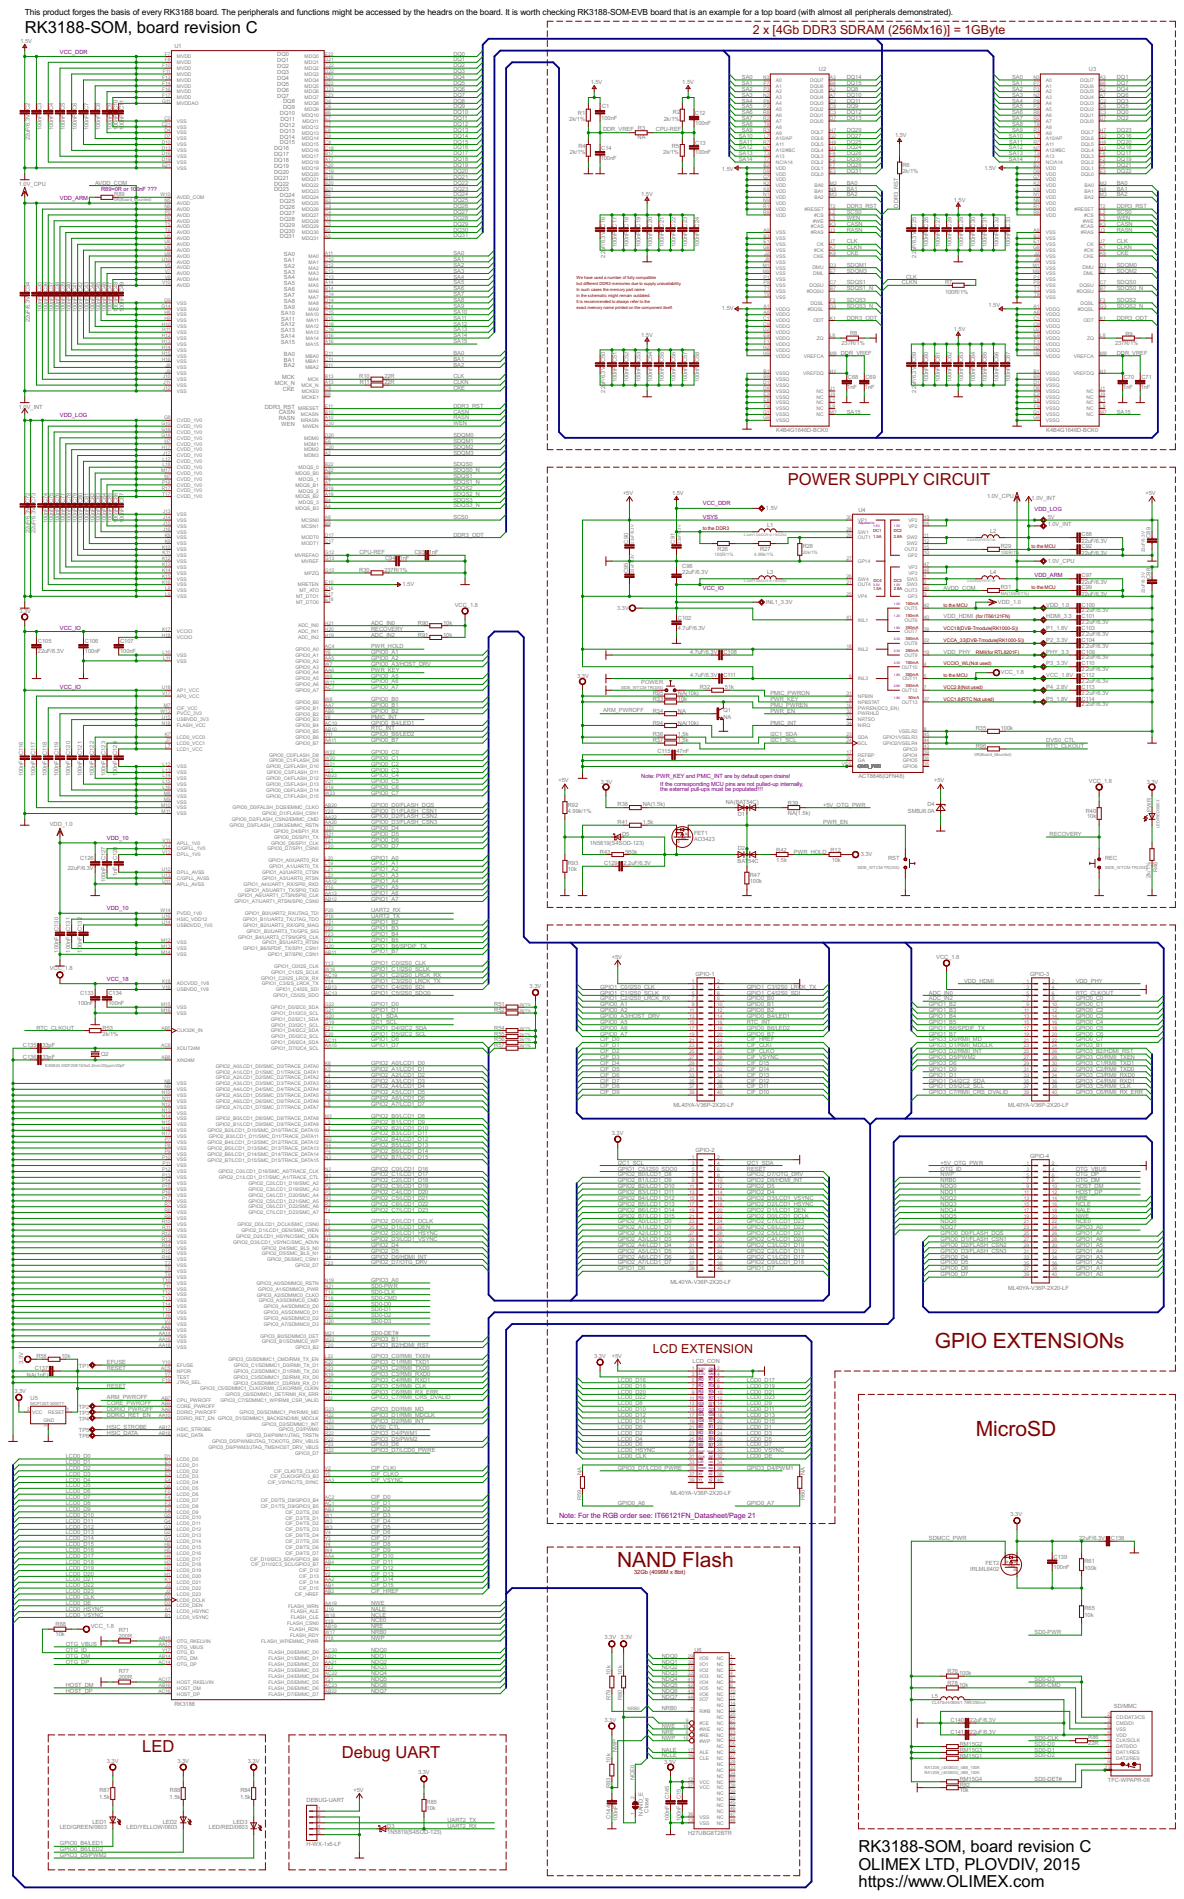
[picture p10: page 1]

This product forges the basis of every RK3188 board. The peripherals and functions might be accessed by the headrs on the board. It is worth checking RK3188-SOM-EVB board that is an example for a top board (with almost all peripherals demonstrated).
RK3188-SOM, board revision C

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

It is recommended to always refer to the
exact memory name printed on the component itself.

K16 | VCC_IO

VCC1.8(RTC Not used) VCC2.8(Not used) VCCIO_WL(Not used) RMII(for RTL8201F) VCCA_33(DVB-Tmodule(RK1000-S)) VCC18(DVB-Tmodule(RK1000-S))

Note: PWR_KEY and PMIC_INT are by default open drains!

If the corresponding MCU pins are not pulled-up internally,
the external pull-ups must be populated!!!

GPIO EXTENSIONs LCD EXTENSION

Note: For the RGB order see: IT66121FN_Datasheet/Page 21

OLIMEX LTD, PLOVDIV, 2015
https://www.OLIMEX.com

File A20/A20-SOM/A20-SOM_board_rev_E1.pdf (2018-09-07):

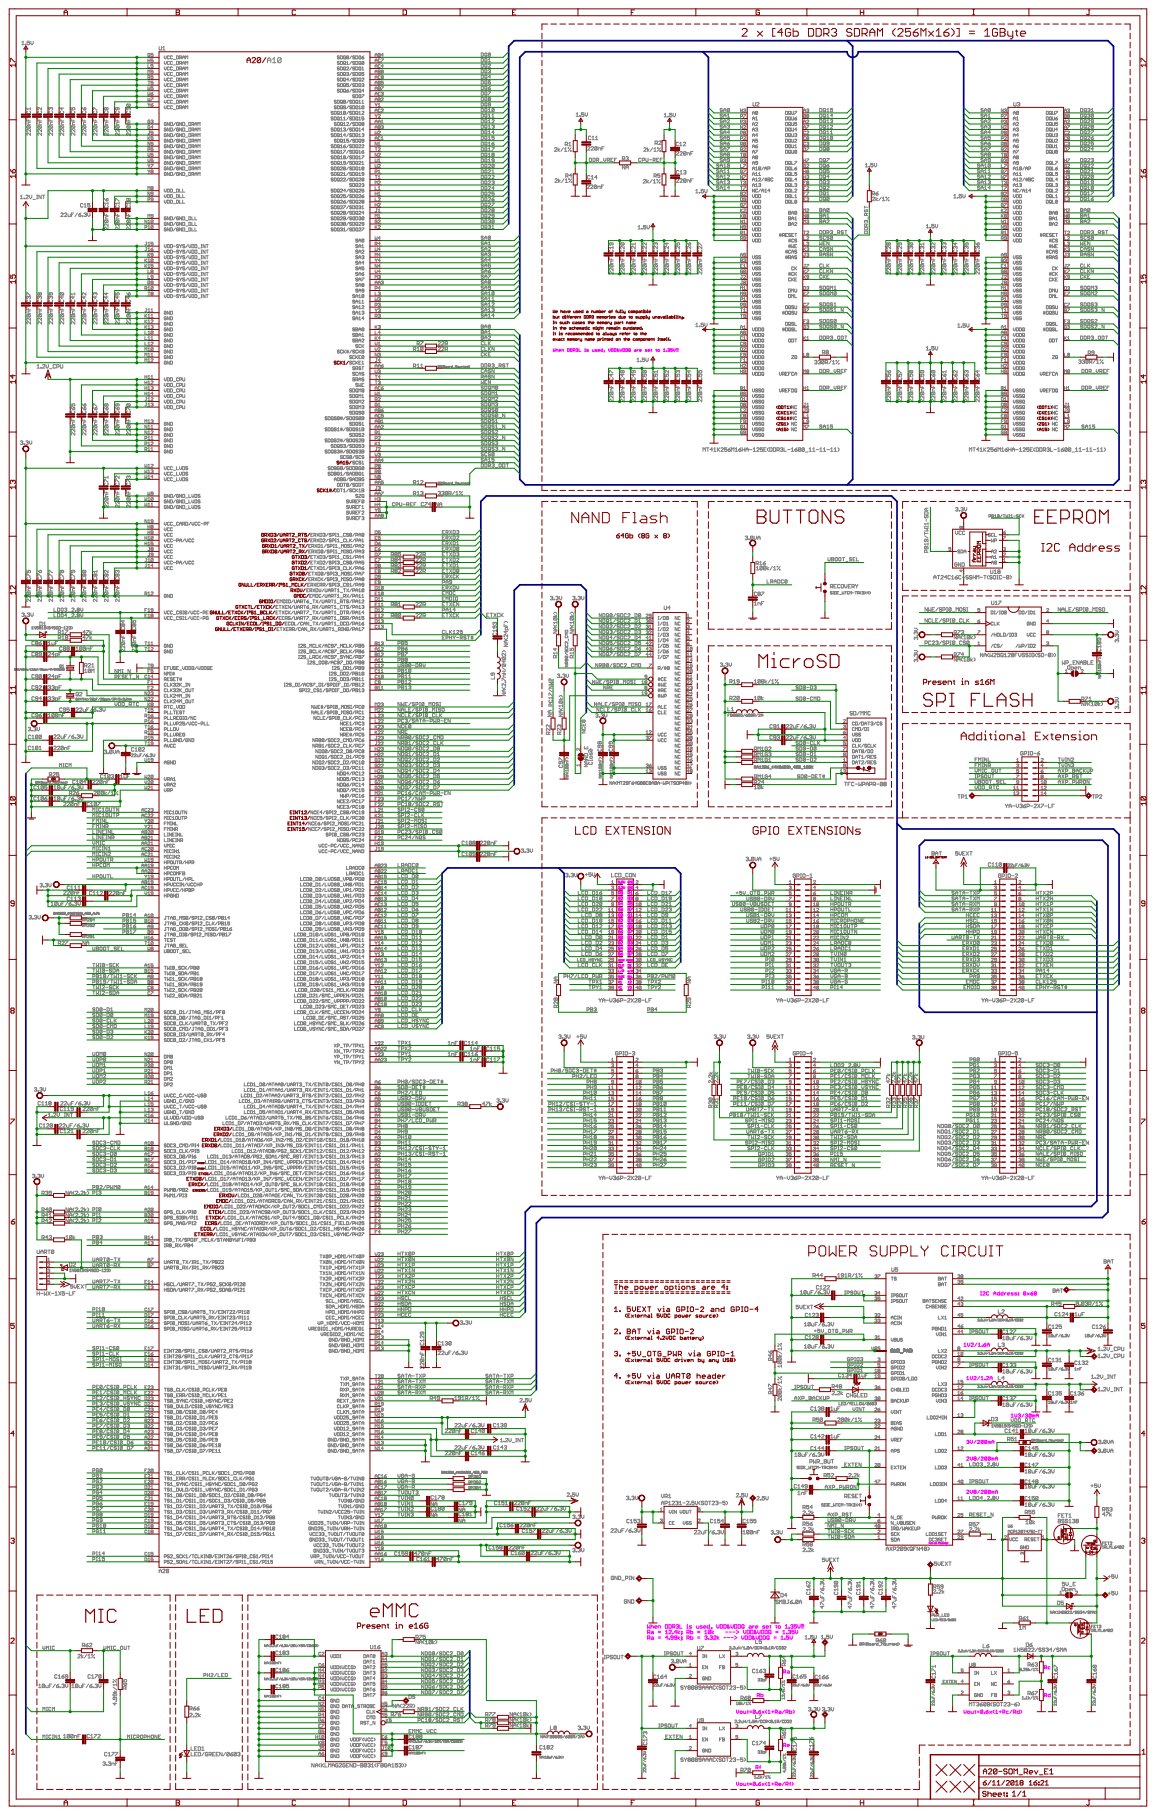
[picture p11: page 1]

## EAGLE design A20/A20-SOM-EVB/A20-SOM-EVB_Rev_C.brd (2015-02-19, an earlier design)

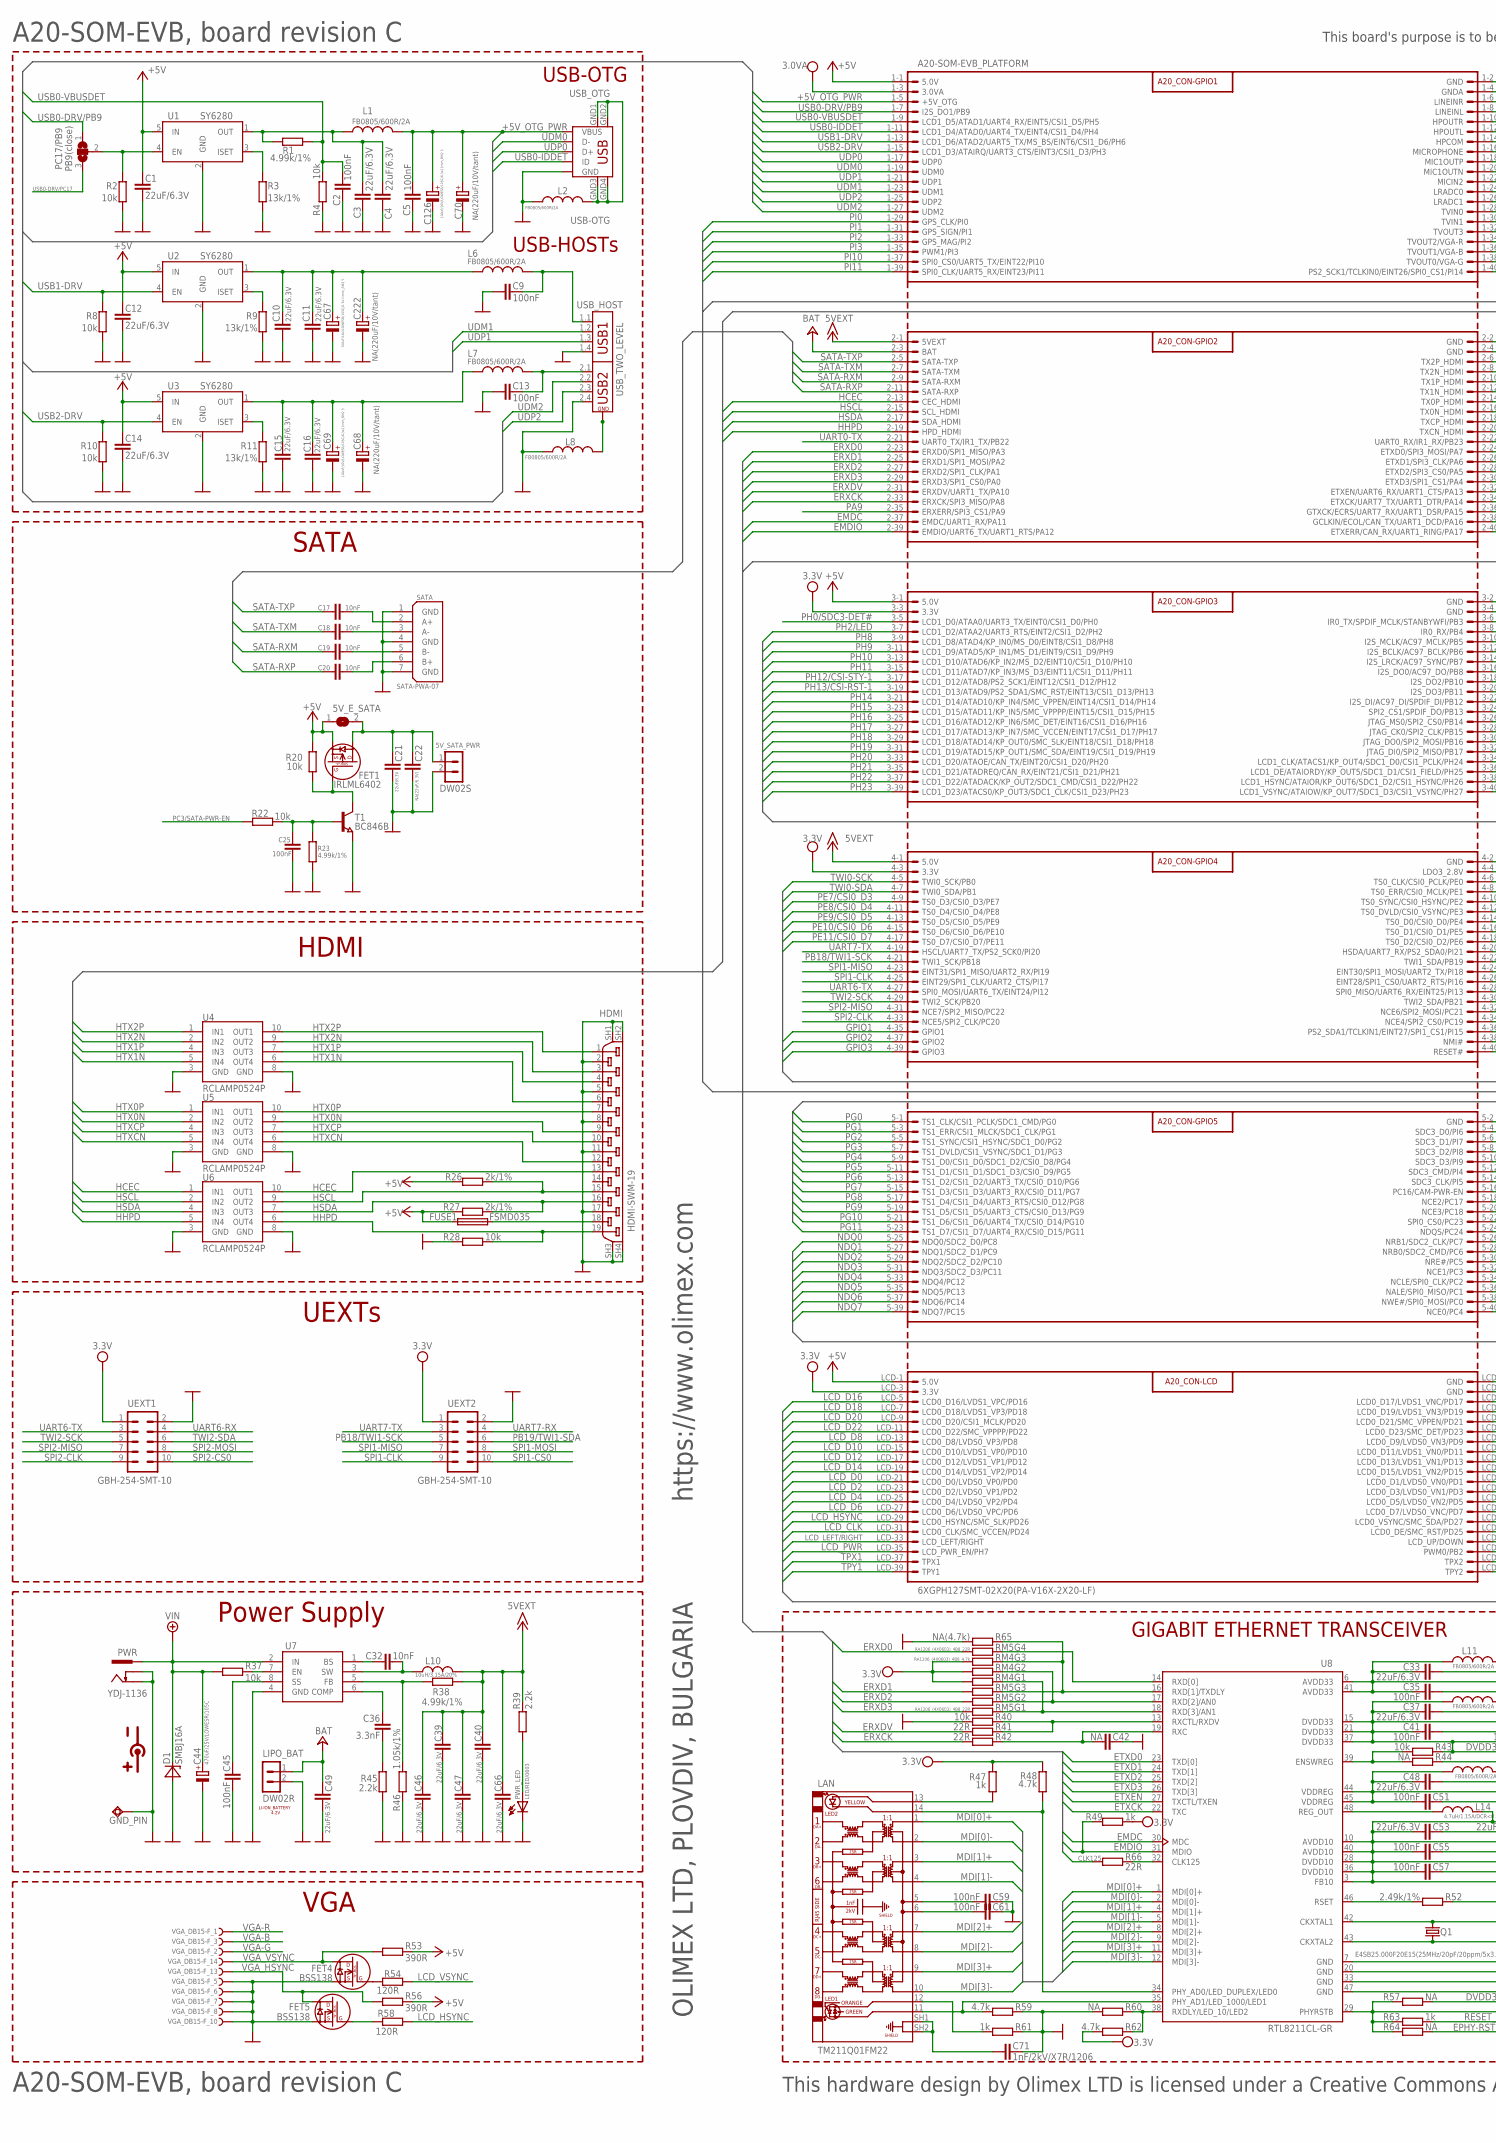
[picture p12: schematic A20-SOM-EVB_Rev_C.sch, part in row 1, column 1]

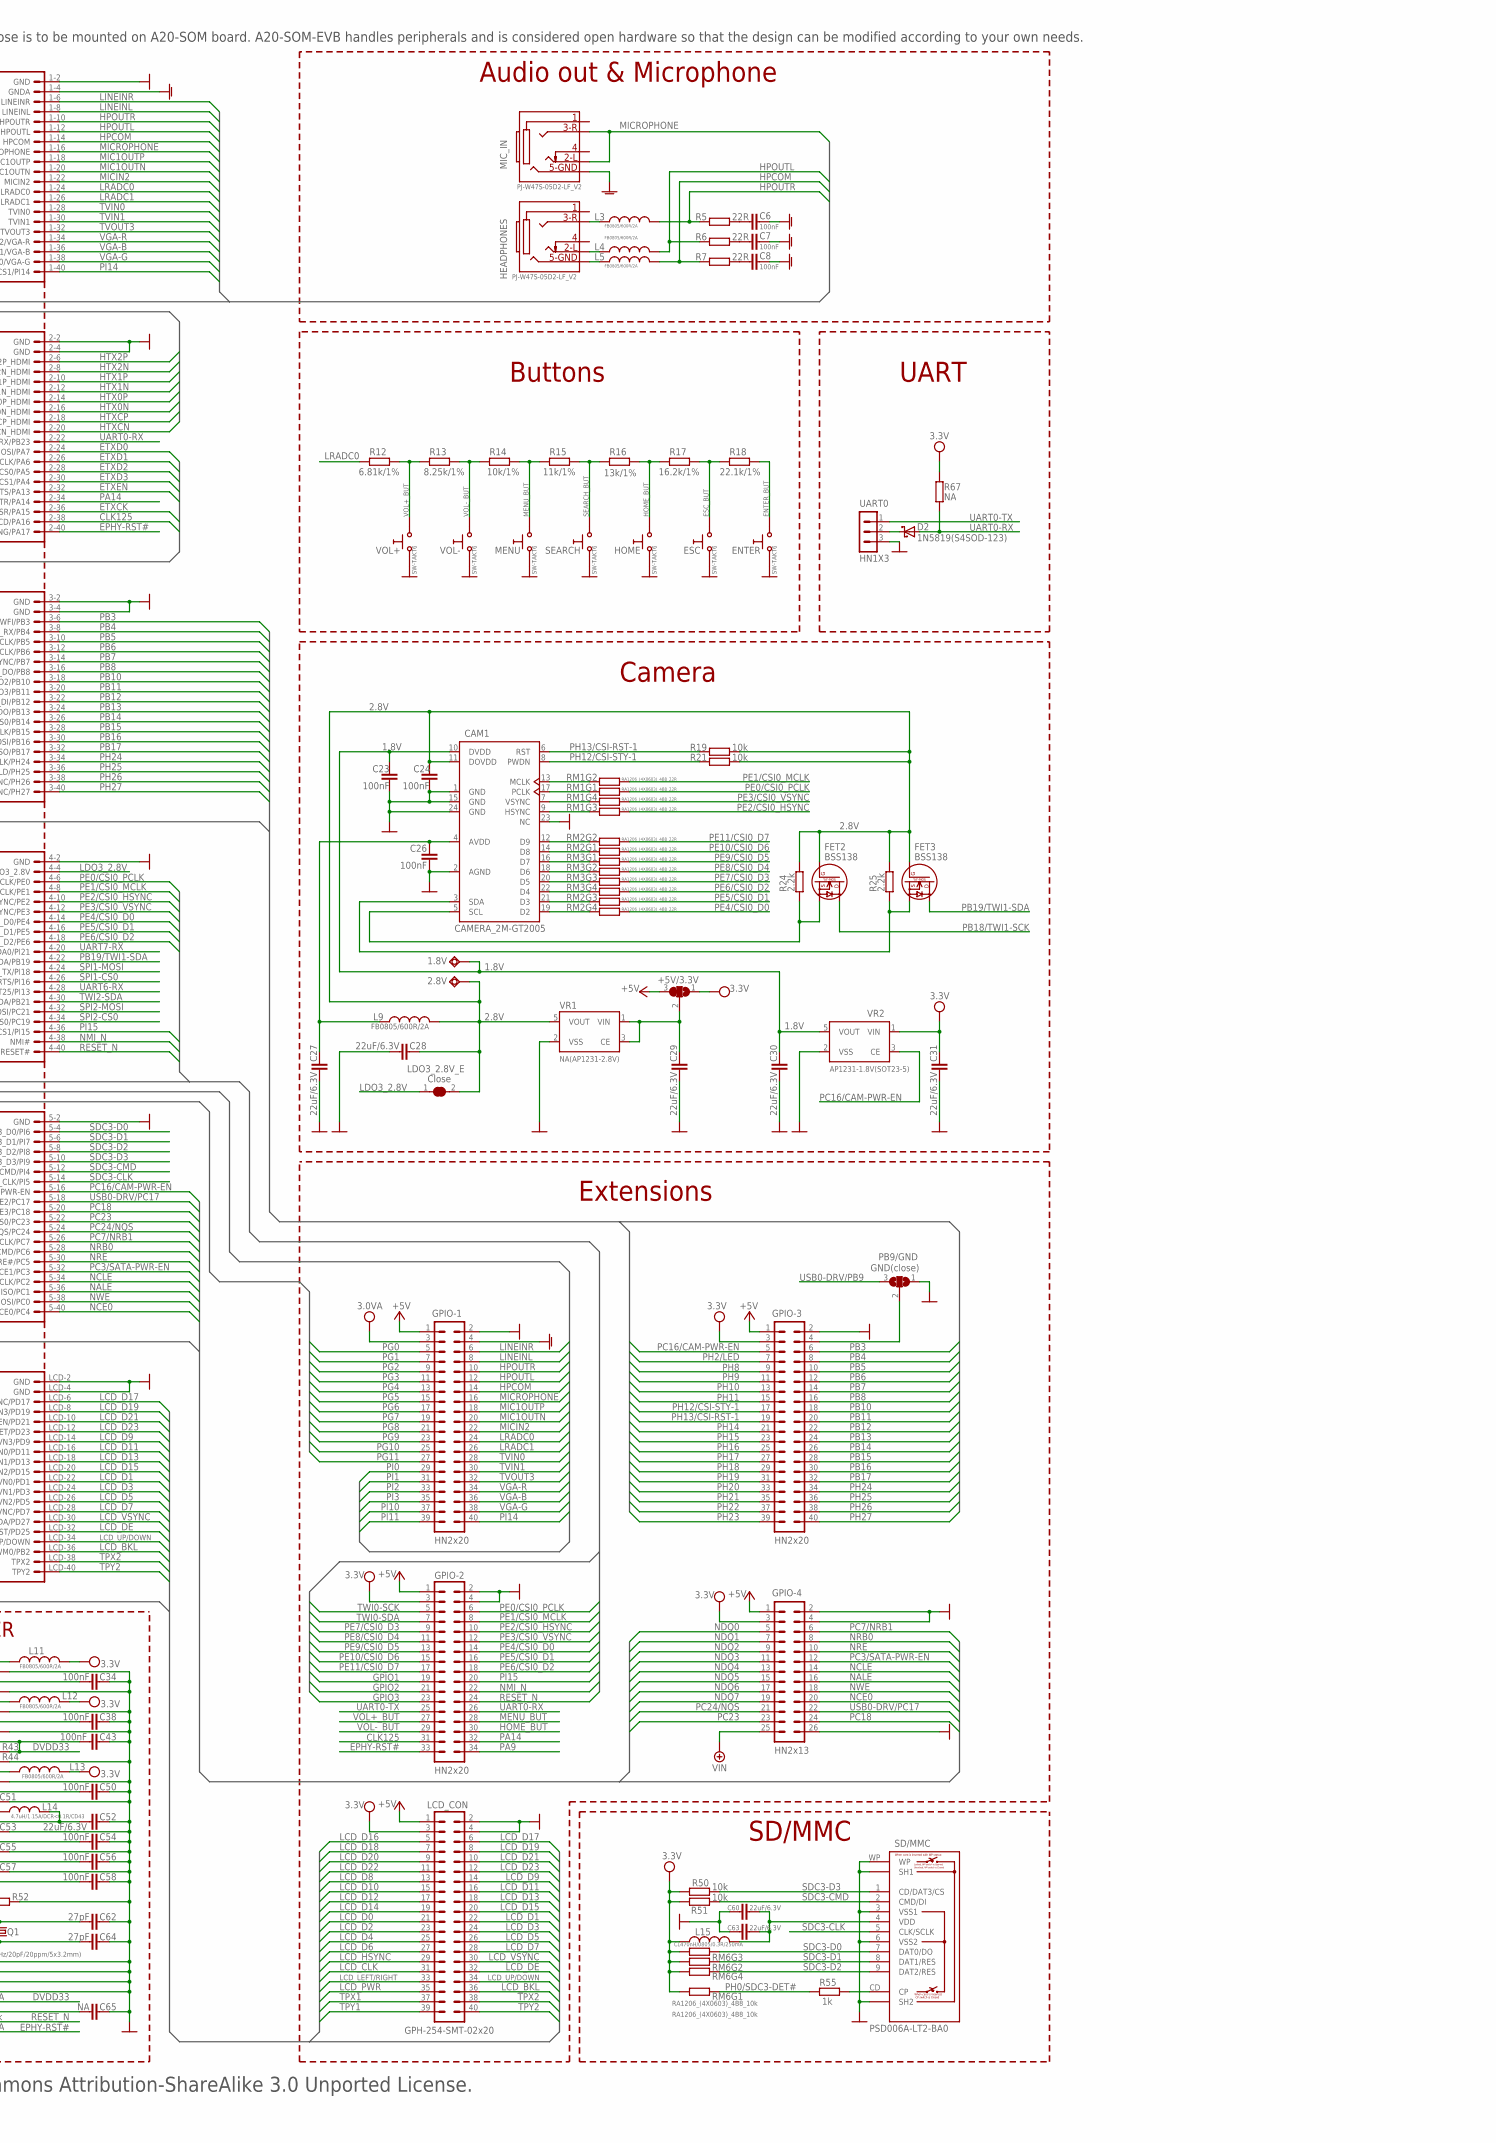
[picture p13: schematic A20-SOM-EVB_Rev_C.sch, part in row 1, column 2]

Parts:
1.8V, 2.8V: TESTPAD80/40; SMD80/40
5V_E_SATA: SJSJ_SMALLER; SJ_1_SMALLER
5V_SATA_PWR: DW02S
+5V/3.3V: SJ2W8; SJ_2_SMALLER_23_TIED
A20-SOM-EVB_PLATFORM: 6XGPH127SMT-02X20(PA-V16X-2X20-LF); A20-SOM-EVB
C1, C3, C4, C10, C11, C12, C14, C15, C16, C21, C27, C28, C29, C30, C31, C33, C37, C39, C40, C46, C47, C48, C49, C52, C53, C60, C63, C66: 22uF/6.3V; C0603_DWS
C2, C5, C6, C7, C8, C9, C13, C23, C24, C25, C26, C34, C35, C38, C41, C43, C45, C50, C51, C54, C55, C56, C57, C58, C59, C61: 100nF; C0603_DWS
C17, C18, C19, C20, C32: 10nF; C0603_DWS
C22: NA(22uF/6.3V); C0603_DWS
C36: 3.3nF; C0603_DWS
C42, C65: NA; C0603_DWS
C44: 470uF/25V/LOWESR/105C; E3,5-8
C62, C64: 27pF; C0603_DWS
C67, C69, C126: 100uF/16V/LOWESR/105C/6.3x11mm_RM2.5; E2,5-6,3
C68, C70, C222: NA(220uF/10V/tant); CT7343
C71: 1nF/2kV/X7R/1206; C1206_5MILS_WS_ISO
CAM1: CAMERA_2M-GT2005; CAM_2M_GT2005
D1: SMBJ16A; DO214AA
D2: 1N5819(S4SOD-123); SOD-123
ENTER: SW-TAKT6; SW-TAKT_6X3.5_SMD
ESC: SW-TAKT6; SW-TAKT_6X3.5_SMD
FET1: IRLML6402; SOT23
FET2, FET3, FET4, FET5: BSS138; SOT23
FUSE1: FSMD035; 1206
GND_PIN: TESTPAD3; TEST_PAD40/70/SQUARE
GPIO-1, GPIO-3: HN2x20; ML40-MALE(GBH-254-SMT-40)
GPIO-2: HN2x20; ML34-MALE(GBH-254-SMT-34)
GPIO-4: HN2x13; ML26-MALE(GBH-254-SMT-26)
HDMI: HDMI-SWM-19
HEADPHONES: PJ-W47S-05D2-LF_V2; PJ-W47S-05D2-LF_5PIN_V2
HOME: SW-TAKT6; SW-TAKT_6X3.5_SMD
L1, L2, L3, L4, L5, L6, L7, L8, L9, L11, L12, L13: FB0805/600R/2A; L0805_5MIL_DWS
L10: 10uH/3.15A/20%; 8X7MM_3131
L14: 4.7uH/1.15A/DCR<0.1R/CD43; CD42(43)
L15: CL470nH/0805/0.3R/250mA; L0805_5MIL_DWS
LAN: TM211Q01FM22; TM211Q01FM22_SH
LCD_CON: GPH-254-SMT-02x20; ML40-MALE(GBH-254-SMT-40)
LDO3_2.8V_E: Close; SJ_1_SMALLER_CLOSE
LIPO_BAT: DW02R
MENU: SW-TAKT6; SW-TAKT_6X3.5_SMD
MIC_IN: PJ-W47S-05D2-LF_V2; PJ-W47S-05D2-LF_5PIN_V2
PB9/GND: GND(close); SJ_2_SMALL
PC17/PB9: PB9(close); SJ_2_SMALL
PWR: YDJ-1136; PWR_JACK_UNI_MILLING
PWR_LED: LED/RED/0603; LED-0603
Q1: E4SB25.000F20E15(25MHz/20pF/20ppm/5x3.2mm); HCX-4S
R1, R23, R38: 4.99k/1%; R0603_5MIL_DWS
R2, R4, R8, R10, R19, R20, R21, R22, R28, R37, R40, R43, R50, R51: 10k; R0603_5MIL_DWS
R3, R9, R11, R16: 13k/1%; R0603_5MIL_DWS
R5, R6, R7, R41, R42, R66: 22R; R0603_5MIL_DWS
R12: 6.81k/1%; R0603_5MIL_DWS
R13: 8.25k/1%; R0603_5MIL_DWS
R14: 10k/1%; R0603_5MIL_DWS
R15: 11k/1%; R0603_5MIL_DWS
R17: 16.2k/1%; R0603_5MIL_DWS
R18: 22.1k/1%; R0603_5MIL_DWS
R24, R25, R39, R45: 2.2k; R0603_5MIL_DWS
R26, R27: 2k/1%; R0603_5MIL_DWS
R44, R57, R60, R64, R67: NA; R0603_5MIL_DWS
R46: 1.05k/1%; R0603_5MIL_DWS
R47, R49, R55, R61, R63: 1k; R0603_5MIL_DWS
R48, R59, R62: 4.7k; R0603_5MIL_DWS
R52: 2.49k/1%; R0603_5MIL_DWS
R53, R56: 390R; R0603_5MIL_DWS
R54, R58: 120R; R0603_5MIL_DWS
R65: NA(4.7k); R0603_5MIL_DWS
RM1, RM2, RM3, RM5: RA1206_(4X0603)_4B8_22R; R_MATRIX_4
RM4: RA1206_(4X0603)_4B8_4.7k; R_MATRIX_4
RM6: RA1206_(4X0603)_4B8_10k; R_MATRIX_4
SATA: SATA-PWA-07
SD/MMC: PSD006A-LT2-BA0; SD_CARD
SEARCH: SW-TAKT6; SW-TAKT_6X3.5_SMD
T1: BC846B; SOT23
U1, U2, U3: SY6280; SOT23-5
U4, U5, U6: RCLAMP0524P; SLP2510P8
U7: MP1482DS; SOIC8
U8: RTL8211CL-GR; LQFP48
UART0: HN1X3
UEXT1, UEXT2: GBH-254-SMT-10; ML10_S
USB_HOST: USB_TWO_LEVEL
USB_OTG: USB-OTG; USB_MINI_9PIN
VGA_DB15-F: VGA15; DB15-F_22MM
VOL+: SW-TAKT6; SW-TAKT_6X3.5_SMD
VOL-: SW-TAKT6; SW-TAKT_6X3.5_SMD
VR1: NA(AP1231-2.8V); SOT-23-5
VR2: AP1231-1.8V(SOT23-5); SOT-23-5

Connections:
1.8V: 1.8V.P$1, C23.1, C30.1, CAM1.10 (DVDD), VR2.5 (VOUT)
2.8V: 2.8V.P$1, C24.1, C28.1, CAM1.11 (DOVDD), FET2.1 (G), FET3.1 (G), L9.2, LDO3_2.8V_E.2, R19.2, R21.2, R24.2, R25.2, VR1.5 (VOUT)
+5V: 5V_E_SATA.1, +5V/3.3V.3, A20-SOM-EVB_PLATFORM.1-1 (5.0V), A20-SOM-EVB_PLATFORM.3-1 (5.0V), A20-SOM-EVB_PLATFORM.LCD-1 (5.0V), C1.1, C12.1, C14.1, FET1.2 (S), FUSE1.1, GPIO-1.1, GPIO-2.1, GPIO-3.1, GPIO-4.1, LCD_CON.1, R20.1, R26.2, R27.2, R53.1, R56.1, U1.5 (IN), U2.5 (IN), U3.5 (IN)
+5V_OTG_PWR: A20-SOM-EVB_PLATFORM.1-5 (+5V_OTG), C5.1, C70.+, C126.+, L1.1, USB_OTG.VBUS
+12V: C44.+, D1.C, GPIO-4.25, PWR.+, R37.1, U7.2 (IN)
+15V: A20-SOM-EVB_PLATFORM.2-1 (5VEXT), A20-SOM-EVB_PLATFORM.4-1 (5.0V), C39.1, C40.1, C46.1, C47.1, C66.1, L10.2, R38.2, R39.1
+24V: A20-SOM-EVB_PLATFORM.2-3 (BAT), C49.2, LIPO_BAT.1
AVDD1: C26.1, C27.1, CAM1.4 (AVDD), L9.1
AVDD33: C33.2, C34.2, C35.2, L11.2, U8.6 (AVDD33), U8.41 (AVDD33)
AVDD/DVDD(1.05V): C52.2, C53.2, C54.2, C55.2, C56.2, C57.2, C58.2, L14.2, U8.3 (FB10), U8.10 (AVDD10), U8.28 (DVDD10), U8.36 (DVDD10), U8.40 (AVDD10)
CLK125: A20-SOM-EVB_PLATFORM.2-38 (GCLKIN/ECOL/CAN_TX/UART1_DCD/PA16), GPIO-2.31, R66.1
DVDD33: C37.2, C38.2, C41.2, C43.2, L12.2, R43.1, R57.1, U8.15 (DVDD33), U8.21 (DVDD33), U8.37 (DVDD33)
EMDC: A20-SOM-EVB_PLATFORM.2-37 (EMDC/UART1_RX/PA11), U8.30 (MDC)
EMDIO: A20-SOM-EVB_PLATFORM.2-39 (EMDIO/UART6_TX/UART1_RTS/PA12), R49.1, U8.31 (MDIO)
ENTER_BUT: ENTER.P$2 (1), R18.2
EPHY-RST#: A20-SOM-EVB_PLATFORM.2-40 (ETXERR/CAN_RX/UART1_RING/PA17), GPIO-2.33, R64.1
ERXCK: A20-SOM-EVB_PLATFORM.2-33 (ERXCK/SPI3_MISO/PA8), R42.2
ERXD0: A20-SOM-EVB_PLATFORM.2-23 (ERXD0/SPI1_MISO/PA3), RM5.4.2 (2)
ERXD1: A20-SOM-EVB_PLATFORM.2-25 (ERXD1/SPI1_MOSI/PA2), RM5.3.2 (2)
ERXD2: A20-SOM-EVB_PLATFORM.2-27 (ERXD2/SPI1_CLK/PA1), RM5.2.2 (2)
ERXD3: A20-SOM-EVB_PLATFORM.2-29 (ERXD3/SPI1_CS0/PA0), RM5.1.2 (2)
ERXDV: A20-SOM-EVB_PLATFORM.2-31 (ERXDV/UART1_TX/PA10), R41.2
ESC_BUT: ESC.P$2 (1), R17.2, R18.1
ETXCK: A20-SOM-EVB_PLATFORM.2-36 (GTXCK/ECRS/UART7_RX/UART1_DSR/PA15), U8.22 (TXC)
ETXD0: A20-SOM-EVB_PLATFORM.2-24 (ETXD0/SPI3_MOSI/PA7), U8.23 (TXD[0])
ETXD1: A20-SOM-EVB_PLATFORM.2-26 (ETXD1/SPI3_CLK/PA6), U8.24 (TXD[1])
ETXD2: A20-SOM-EVB_PLATFORM.2-28 (ETXD2/SPI3_CS0/PA5), U8.25 (TXD[2])
ETXD3: A20-SOM-EVB_PLATFORM.2-30 (ETXD3/SPI1_CS1/PA4), U8.26 (TXD[3])
ETXEN: A20-SOM-EVB_PLATFORM.2-32 (ETXEN/UART6_RX/UART1_CTS/PA13), U8.27 (TXCTL/TXEN)
GND: 5V_SATA_PWR.2, A20-SOM-EVB_PLATFORM.1-2 (GND), A20-SOM-EVB_PLATFORM.2-2 (GND), A20-SOM-EVB_PLATFORM.2-4 (GND), A20-SOM-EVB_PLATFORM.3-2 (GND), A20-SOM-EVB_PLATFORM.3-4 (GND), A20-SOM-EVB_PLATFORM.4-2 (GND), A20-SOM-EVB_PLATFORM.5-2 (GND), A20-SOM-EVB_PLATFORM.LCD-2 (GND), A20-SOM-EVB_PLATFORM.LCD-4 (GND), C1.2, C2.2, C3.2, C4.2, C5.2, C9.2, C10.2, C11.2, C12.2, C13.2, C14.2, C15.2, C16.2, C21.1, C22.1, C23.2, C24.2, C25.2, C26.2, C27.2, C28.2, C29.2, C30.2, C31.2, C33.1, C34.1, C35.1, C37.1, C38.1, C39.2, C40.2, C41.1, C42.2, C43.1, C44.-, C45.2, C46.2, C47.2, C48.1, C49.1, C50.1, C51.1, C52.1, C53.1, C54.1, C55.1, C56.1, C57.1, C58.1, C59.1, C60.1, C61.1, C62.1, C63.1, C64.1, C65.1, C66.2, C67.-, C68.-, C69.-, C70.-, C71.1, C126.-, C222.-, CAM1.1 (GND), CAM1.2 (AGND), CAM1.15 (GND), CAM1.23 (NC), CAM1.24 (GND), D1.A, ENTER.P$1 (0), ESC.P$1 (0), FET4.2 (S), FET5.2 (S), GND_PIN.P$1, GPIO-1.2, GPIO-2.2, GPIO-2.4, GPIO-3.2, GPIO-4.2, GPIO-4.4, GPIO-4.26, HDMI.2, HDMI.5, HDMI.8, HDMI.11, HDMI.17, HDMI.SH1 (20), HDMI.SH2 (21), HDMI.SH3 (22), HDMI.SH4 (23), HOME.P$1 (0), L2.1, L8.1, LCD_CON.2, LCD_CON.4, LIPO_BAT.2, MENU.P$1 (0), PB9/GND.1, PWR.-, PWR.--, PWR_LED.C, R2.1, R3.1, R4.1, R8.1, R9.1, R10.1, R11.1, R23.1, R28.2, R40.2, R44.1, R45.2, R46.2, R52.1, R59.1, R60.2, R61.1, R65.2, SATA.1 (GND), SATA.4 (GND), SATA.7 (GND), SD/MMC.3 (VSS1), SD/MMC.6 (VSS2), SD/MMC.SH1, SD/MMC.SH2, SD/MMC.WP, SEARCH.P$1 (0), T1.2 (E), U1.2 (GND), U2.2 (GND), U3.2 (GND), U4.3 (GND), U4.8 (GND), U5.3 (GND), U5.8 (GND), U6.3 (GND), U6.8 (GND), U7.4 (GND), U8.7 (GND), U8.20 (GND), U8.33 (GND), U8.47 (GND), UART0.3, UEXT1.2, UEXT2.2, USB_HOST.1.4, USB_HOST.2.4, USB_OTG.GND, VGA_DB15-F.5 (F), VGA_DB15-F.6 (F), VGA_DB15-F.7 (F), VGA_DB15-F.8 (F), VGA_DB15-F.10 (F), VGA_DB15-F.GND1 (GND), VGA_DB15-F.GND2 (GND), VOL+.P$1 (0), VOL-.P$1 (0), VR1.2 (VSS), VR2.2 (VSS)
GNDA: A20-SOM-EVB_PLATFORM.1-4 (GNDA), C6.1, C7.1, C8.1, GPIO-1.4, MIC_IN.5
GPIO1: A20-SOM-EVB_PLATFORM.4-35 (GPIO1), GPIO-2.19
GPIO2: A20-SOM-EVB_PLATFORM.4-37 (GPIO2), GPIO-2.21
GPIO3: A20-SOM-EVB_PLATFORM.4-39 (GPIO3), GPIO-2.23
HCEC: A20-SOM-EVB_PLATFORM.2-13 (CEC_HDMI), HDMI.13, U6.1 (IN1), U6.10 (OUT1)
HDMI_5V_SOURCE: FUSE1.2, HDMI.18
HHPD: A20-SOM-EVB_PLATFORM.2-19 (HPD_HDMI), HDMI.19, R28.1, U6.5 (IN4), U6.6 (OUT4)
HOME_BUT: GPIO-2.30, HOME.P$2 (1), R16.2, R17.1
HPCOM: A20-SOM-EVB_PLATFORM.1-14 (HPCOM), GPIO-1.14, L5.1, R7.2
HPOUTL: A20-SOM-EVB_PLATFORM.1-12 (HPOUTL), GPIO-1.12, L4.1, R6.2
HPOUTR: A20-SOM-EVB_PLATFORM.1-10 (HPOUTR), GPIO-1.10, L3.1, R5.2
HSCL: A20-SOM-EVB_PLATFORM.2-15 (SCL_HDMI), HDMI.15, R26.1, U6.2 (IN2), U6.9 (OUT2)
HSDA: A20-SOM-EVB_PLATFORM.2-17 (SDA_HDMI), HDMI.16, R27.1, U6.4 (IN3), U6.7 (OUT3)
HTX0N: A20-SOM-EVB_PLATFORM.2-16 (TX0N_HDMI), HDMI.9, U5.2 (IN2), U5.9 (OUT2)
HTX0P: A20-SOM-EVB_PLATFORM.2-14 (TX0P_HDMI), HDMI.7, U5.1 (IN1), U5.10 (OUT1)
HTX1N: A20-SOM-EVB_PLATFORM.2-12 (TX1N_HDMI), HDMI.6, U4.5 (IN4), U4.6 (OUT4)
HTX1P: A20-SOM-EVB_PLATFORM.2-10 (TX1P_HDMI), HDMI.4, U4.4 (IN3), U4.7 (OUT3)
HTX2N: A20-SOM-EVB_PLATFORM.2-8 (TX2N_HDMI), HDMI.3, U4.2 (IN2), U4.9 (OUT2)
HTX2P: A20-SOM-EVB_PLATFORM.2-6 (TX2P_HDMI), HDMI.1, U4.1 (IN1), U4.10 (OUT1)
HTXCN: A20-SOM-EVB_PLATFORM.2-20 (TXCN_HDMI), HDMI.12, U5.5 (IN4), U5.6 (OUT4)
HTXCP: A20-SOM-EVB_PLATFORM.2-18 (TXCP_HDMI), HDMI.10, U5.4 (IN3), U5.7 (OUT3)
LCD_BKL: A20-SOM-EVB_PLATFORM.LCD-36 (PWM0/PB2), LCD_CON.36
LCD_CLK: A20-SOM-EVB_PLATFORM.LCD-31 (LCD0_CLK/SMC_VCCEN/PD24), LCD_CON.31
LCD_D0: A20-SOM-EVB_PLATFORM.LCD-21 (LCD0_D0/LVDS0_VP0/PD0), LCD_CON.21
LCD_D1: A20-SOM-EVB_PLATFORM.LCD-22 (LCD0_D1/LVDS0_VN0/PD1), LCD_CON.22
LCD_D2: A20-SOM-EVB_PLATFORM.LCD-23 (LCD0_D2/LVDS0_VP1/PD2), LCD_CON.23
LCD_D3: A20-SOM-EVB_PLATFORM.LCD-24 (LCD0_D3/LVDS0_VN1/PD3), LCD_CON.24
LCD_D4: A20-SOM-EVB_PLATFORM.LCD-25 (LCD0_D4/LVDS0_VP2/PD4), LCD_CON.25
LCD_D5: A20-SOM-EVB_PLATFORM.LCD-26 (LCD0_D5/LVDS0_VN2/PD5), LCD_CON.26
LCD_D6: A20-SOM-EVB_PLATFORM.LCD-27 (LCD0_D6/LVDS0_VPC/PD6), LCD_CON.27
LCD_D7: A20-SOM-EVB_PLATFORM.LCD-28 (LCD0_D7/LVDS0_VNC/PD7), LCD_CON.28
LCD_D8: A20-SOM-EVB_PLATFORM.LCD-13 (LCD0_D8/LVDS0_VP3/PD8), LCD_CON.13
LCD_D9: A20-SOM-EVB_PLATFORM.LCD-14 (LCD0_D9/LVDS0_VN3/PD9), LCD_CON.14
LCD_D10: A20-SOM-EVB_PLATFORM.LCD-15 (LCD0_D10/LVDS1_VP0/PD10), LCD_CON.15
LCD_D11: A20-SOM-EVB_PLATFORM.LCD-16 (LCD0_D11/LVDS1_VN0/PD11), LCD_CON.16
LCD_D12: A20-SOM-EVB_PLATFORM.LCD-17 (LCD0_D12/LVDS1_VP1/PD12), LCD_CON.17
LCD_D13: A20-SOM-EVB_PLATFORM.LCD-18 (LCD0_D13/LVDS1_VN1/PD13), LCD_CON.18
LCD_D14: A20-SOM-EVB_PLATFORM.LCD-19 (LCD0_D14/LVDS1_VP2/PD14), LCD_CON.19
LCD_D15: A20-SOM-EVB_PLATFORM.LCD-20 (LCD0_D15/LVDS1_VN2/PD15), LCD_CON.20
LCD_D16: A20-SOM-EVB_PLATFORM.LCD-5 (LCD0_D16/LVDS1_VPC/PD16), LCD_CON.5
LCD_D17: A20-SOM-EVB_PLATFORM.LCD-6 (LCD0_D17/LVDS1_VNC/PD17), LCD_CON.6
LCD_D18: A20-SOM-EVB_PLATFORM.LCD-7 (LCD0_D18/LVDS1_VP3/PD18), LCD_CON.7
LCD_D19: A20-SOM-EVB_PLATFORM.LCD-8 (LCD0_D19/LVDS1_VN3/PD19), LCD_CON.8
LCD_D20: A20-SOM-EVB_PLATFORM.LCD-9 (LCD0_D20/CSI1_MCLK/PD20), LCD_CON.9
LCD_D21: A20-SOM-EVB_PLATFORM.LCD-10 (LCD0_D21/SMC_VPPEN/PD21), LCD_CON.10
LCD_D22: A20-SOM-EVB_PLATFORM.LCD-11 (LCD0_D22/SMC_VPPPP/PD22), LCD_CON.11
LCD_D23: A20-SOM-EVB_PLATFORM.LCD-12 (LCD0_D23/SMC_DET/PD23), LCD_CON.12
LCD_DE: A20-SOM-EVB_PLATFORM.LCD-32 (LCD0_DE/SMC_RST/PD25), LCD_CON.32
LCD_HSYNC: A20-SOM-EVB_PLATFORM.LCD-29 (LCD0_HSYNC/SMC_SLK/PD26), LCD_CON.29, R58.1
LCD_LEFT/RIGHT: A20-SOM-EVB_PLATFORM.LCD-33 (LCD_LEFT/RIGHT), LCD_CON.33
LCD_PWR: A20-SOM-EVB_PLATFORM.LCD-35 (LCD_PWR_EN/PH7), LCD_CON.35
LCD_UP/DOWN: A20-SOM-EVB_PLATFORM.LCD-34 (LCD_UP/DOWN), LCD_CON.34
LCD_VSYNC: A20-SOM-EVB_PLATFORM.LCD-30 (LCD0_VSYNC/SMC_SDA/PD27), LCD_CON.30, R54.1
LDO3_2.8V: A20-SOM-EVB_PLATFORM.4-4 (LDO3_2.8V), LDO3_2.8V_E.1
LINEINL: A20-SOM-EVB_PLATFORM.1-8 (LINEINL), GPIO-1.8
LINEINR: A20-SOM-EVB_PLATFORM.1-6 (LINEINR), GPIO-1.6
LRADC0: A20-SOM-EVB_PLATFORM.1-24 (LRADC0), GPIO-1.24, R12.1
LRADC1: A20-SOM-EVB_PLATFORM.1-26 (LRADC1), GPIO-1.26
MDI[0]+: LAN.1, U8.1 (MDI[0]+)
MDI[0]-: LAN.2, U8.2 (MDI[0]-)
MDI[1]+: LAN.3, U8.4 (MDI[1]+)
MDI[1]-: LAN.4, U8.5 (MDI[1]-)
MDI[2]+: LAN.7, U8.8 (MDI[2]+)
MDI[2]-: LAN.8, U8.9 (MDI[2]-)
MDI[3]+: LAN.9, U8.11 (MDI[3]+)
MDI[3]-: LAN.10, U8.12 (MDI[3]-)
MENU_BUT: GPIO-2.28, MENU.P$2 (1), R14.2, R15.1
MIC1OUTN: A20-SOM-EVB_PLATFORM.1-20 (MIC1OUTN), GPIO-1.20
MIC1OUTP: A20-SOM-EVB_PLATFORM.1-18 (MIC1OUTP), GPIO-1.18
MICIN2: A20-SOM-EVB_PLATFORM.1-22 (MICIN2), GPIO-1.22
MICROPHONE: A20-SOM-EVB_PLATFORM.1-16 (MICROPHONE), GPIO-1.16, MIC_IN.2, MIC_IN.3
unnamed: L2.2, USB_OTG.GND1, USB_OTG.GND2, USB_OTG.GND3, USB_OTG.GND4
unnamed: R3.2, U1.3 (ISET)
unnamed: C3.1, C4.1, L1.2, R1.2, U1.1 (OUT)
unnamed: FET4.1 (G), R54.2
unnamed: FET5.1 (G), R58.2
unnamed: C45.1, U7.8 (SS)
unnamed: R37.2, U7.7 (EN)
unnamed: C32.1, U7.1 (BS)
unnamed: C32.2, L10.1, U7.3 (SW)
unnamed: C36.1, U7.6 (COMP)
unnamed: C36.2, R45.1
unnamed: C71.2, LAN.SH1, LAN.SH2
unnamed: R52.2, U8.46 (RSET)
unnamed: CAM1.3 (SDA), FET3.2 (S), R25.1
unnamed: C62.2, Q1.2, U8.42 (CKXTAL1)
unnamed: C64.2, Q1.1, U8.43 (CKXTAL2)
unnamed: L14.1, U8.48 (REG_OUT)
unnamed: C59.2, LAN.5
unnamed: C65.2, R57.2, R63.2, R64.2, U8.29 (PHYRSTB)
unnamed: C61.2, LAN.6
unnamed: R60.1, R62.1, U8.38 (RXDLY/LED_10/LED2)
unnamed: LAN.12, R61.2
unnamed: LAN.11, R59.2, U8.35 (PHY_AD1/LED_1000/LED1)
unnamed: R43.2, R44.2, U8.39 (ENSWREG)
unnamed: LAN.13, R47.2
unnamed: C42.1, R42.1, U8.19 (RXC)
unnamed: R66.2, U8.32 (CLK125)
unnamed: R40.1, R41.1, U8.13 (RXCTL/RXDV)
unnamed: RM5.4.1 (1), U8.14 (RXD[0])
unnamed: R65.1, RM4.3.1 (1), RM5.3.1 (1), U8.16 (RXD[1]/TXDLY)
unnamed: RM4.2.1 (1), RM5.2.1 (1), U8.17 (RXD[2]/AN0)
unnamed: RM4.1.1 (1), RM5.1.1 (1), U8.18 (RXD[3]/AN1)
unnamed: CAM1.5 (SCL), FET2.2 (S), R24.1
unnamed: CAM1.13 (MCLK), RM1.2.1 (1)
unnamed: CAM1.17 (PCLK), RM1.1.1 (1)
unnamed: CAM1.7 (VSYNC), RM1.4.1 (1)
unnamed: CAM1.9 (HSYNC), RM1.3.1 (1)
unnamed: CAM1.12 (D9), RM2.2.1 (1)
unnamed: CAM1.14 (D8), RM2.1.1 (1)
unnamed: CAM1.16 (D7), RM3.1.1 (1)
unnamed: CAM1.18 (D6), RM3.2.1 (1)
unnamed: CAM1.20 (D5), RM3.3.1 (1)
unnamed: CAM1.22 (D4), RM3.4.1 (1)
unnamed: CAM1.21 (D3), RM2.3.1 (1)
unnamed: CAM1.19 (D2), RM2.4.1 (1)
unnamed: LAN.14, R48.1, U8.34 (PHY_AD0/LED_DUPLEX/LED0)
unnamed: C7.2, R6.1
unnamed: C8.2, R7.1
unnamed: C6.2, R5.1
unnamed: HEADPHONES.5, L5.2
unnamed: HEADPHONES.2, L4.2
unnamed: HEADPHONES.3, L3.2
unnamed: C25.1, R22.1, R23.2, T1.1 (B)
unnamed: FET1.1 (G), R20.2, T1.3 (C)
unnamed: 5V_E_SATA.2, 5V_SATA_PWR.1, C21.2, C22.2, FET1.3 (D)
unnamed: D2.C, UART0.2
unnamed: +5V/3.3V.2, C29.1, VR1.1 (VIN), VR1.3 (CE)
unnamed: GPIO-3.4, PB9/GND.2
unnamed: PC17/PB9.2, R2.2, U1.4 (EN)
unnamed: R38.1, R46.1, U7.5 (FB)
unnamed: R9.2, U2.3 (ISET)
unnamed: C17.2, SATA.2 (A+)
unnamed: C9.1, L6.2, USB_HOST.1.1
unnamed: C18.2, SATA.3 (A-)
unnamed: C19.2, SATA.5 (B-)
unnamed: C20.2, SATA.6 (B+)
unnamed: PWR_LED.A, R39.2
unnamed: R11.2, U3.3 (ISET)
unnamed: R55.1, SD/MMC.CD (CP)
unnamed: C10.1, C11.1, C67.+, C222.+, L6.1, U2.1 (OUT)
unnamed: L8.2, USB_HOST.GND1, USB_HOST.GND2, USB_HOST.GND3, USB_HOST.GND4
unnamed: C13.1, L7.2, USB_HOST.2.1
unnamed: C15.1, C16.1, C68.+, C69.+, L7.1, U3.1 (OUT)
NALE: A20-SOM-EVB_PLATFORM.5-36 (NALE/SPI0_MISO/PC1), GPIO-4.16
NCE0: A20-SOM-EVB_PLATFORM.5-40 (NCE0/PC4), GPIO-4.20
NCLE: A20-SOM-EVB_PLATFORM.5-34 (NCLE/SPI0_CLK/PC2), GPIO-4.14
NDQ0: A20-SOM-EVB_PLATFORM.5-25 (NDQ0/SDC2_D0/PC8), GPIO-4.5
NDQ1: A20-SOM-EVB_PLATFORM.5-27 (NDQ1/SDC2_D1/PC9), GPIO-4.7
NDQ2: A20-SOM-EVB_PLATFORM.5-29 (NDQ2/SDC2_D2/PC10), GPIO-4.9
NDQ3: A20-SOM-EVB_PLATFORM.5-31 (NDQ3/SDC2_D3/PC11), GPIO-4.11
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

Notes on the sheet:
SD/MMC
HDMI
USB-OTG
USB-HOSTs
VGA
Power Supply
UEXTs
GIGABIT ETHERNET TRANSCEIVER
LI-ION_BATTERY
Extensions
4.2V
SATA
Camera
Buttons
Audio out & Microphone
UART
A20-SOM-EVB, board revision C
OLIMEX LTD, PLOVDIV, BULGARIA
https://www.olimex.com
This board's purpose is to be mounted on A20-SOM board. A20-SOM-EVB handles peripherals and is considered open hardware so that the design can be modified according to your own needs.
This hardware design by Olimex LTD is licensed under a Creative Commons Attribution-ShareAlike 3.0 Unported License.

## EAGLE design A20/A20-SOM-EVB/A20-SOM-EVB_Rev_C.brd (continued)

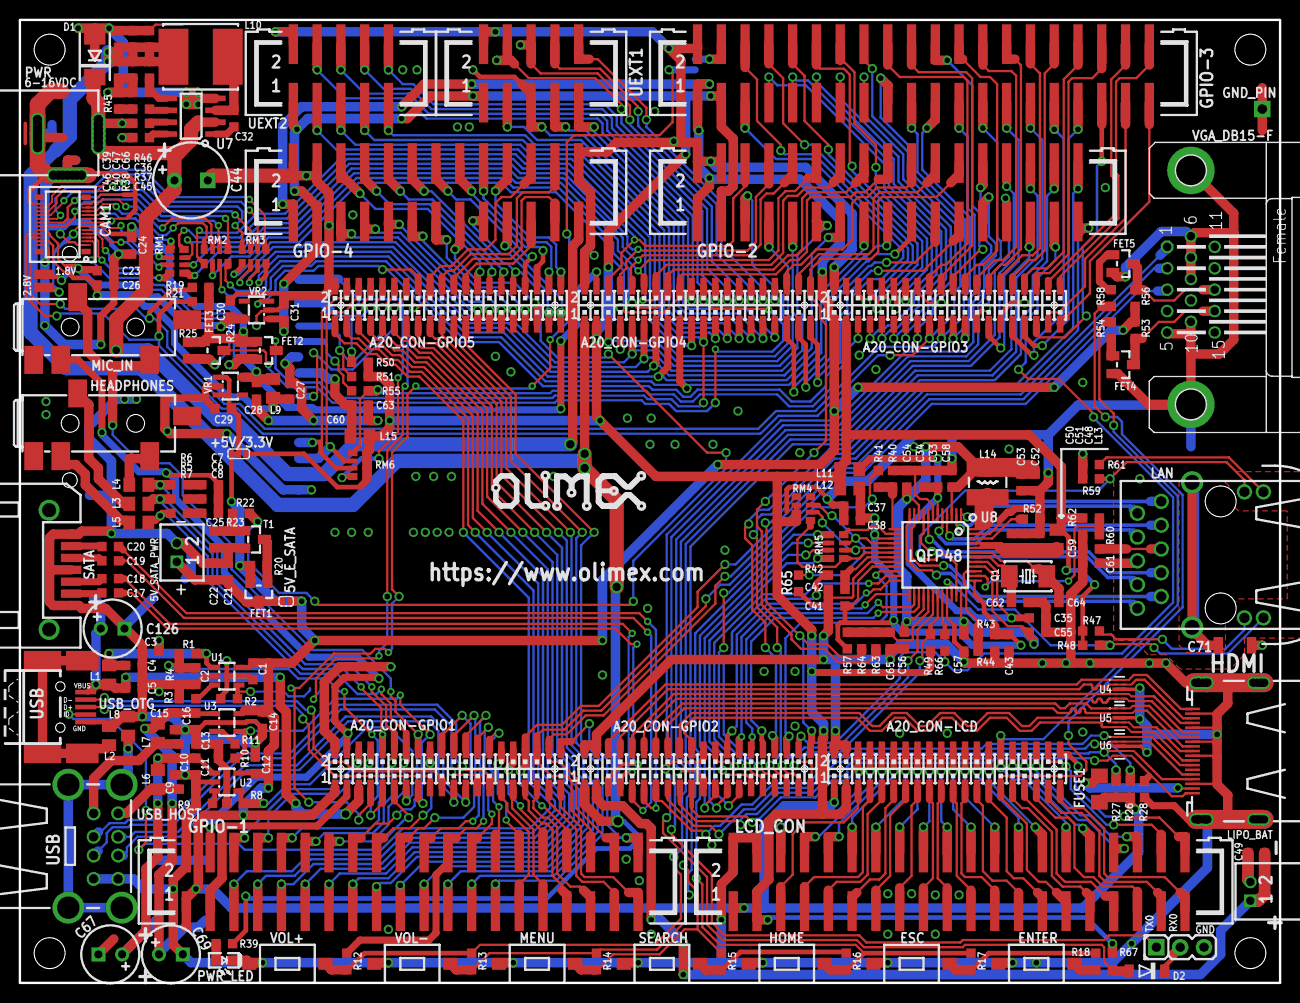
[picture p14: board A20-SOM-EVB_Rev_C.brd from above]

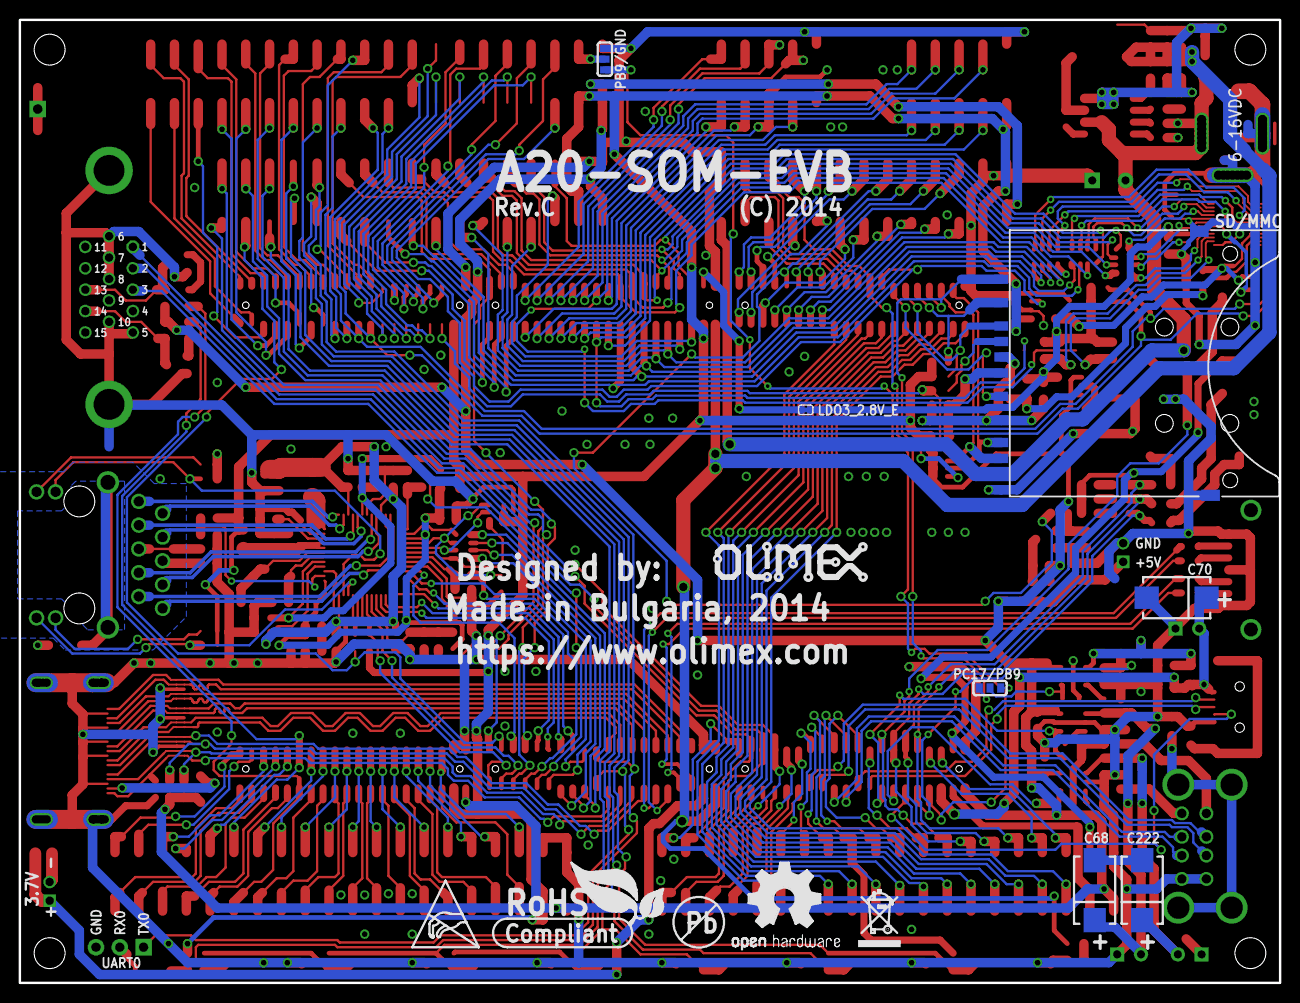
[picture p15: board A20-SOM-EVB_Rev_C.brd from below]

Board: 2 copper layers, 134.6 x 102.9 mm, 218 parts (13 on the bottom side), 327 nets.

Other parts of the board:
U$5: LOGO-OPENHARDWARE_8X8
U$6, U$8: OLIMEX1_V
U$9: PB
U$10: ESD_SYMBOL
U$11: RECYCLE_BIN1/8
U$12: ROHS

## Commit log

2014-06-20 A13-SOM files add
    [A13-SOM-WIFI_Rev_B.brd, A13-SOM-WIFI_Rev_B.sch]
2014-06-25 A13-SOM-LTE shield
    [A13-SOM-LTE_Rev_B.brd, A13-SOM-LTE_Rev_B.sch]
2014-07-28 Various A20-SOM updates.
    [A20-SOM-EVB_Rev_C.brd, A20-SOM-EVB_Rev_C.sch]
2014-10-23 Additional schematics
    Revision B schematics
    [A20-SOM-EVB_Rev_B.brd, A20-SOM-EVB_Rev_B.sch]
2014-12-19 Schematics to newer board revisions A20-SOM
2015-02-19 RK3188 SOM files
    [RK3188-EVB_Rev_C.brd, RK3188-EVB_Rev_C.sch]
2015-03-16 Revision C1
    [RK3188-EVB_Rev_C1.brd, RK3188-EVB_Rev_C1.sch]
2015-03-16 Added files for AM3352
    [AM3352-SOM-EVB_Rev_D.brd, AM3352-SOM-EVB_Rev_D.sch]
2015-03-16 Updated a number of schematics
    [A20-SOM-EVB_Rev_C1.brd, A20-SOM-EVB_Rev_C1.sch]
2015-05-14 kiCAD connector library
2015-05-15 rk3188 kicad library
2015-05-15 kicad connector templates
2015-10-09 Updated latest schematics
    [A13-SOM-LTE_Rev_B1.brd, A13-SOM-LTE_Rev_B1.sch]
2017-06-22 update
    added schematic for the industrial version of the board, note that it
    doesn't have extra flash memory
2020-03-03 Update
    Newer revisions.
    [A20-SOM-EVB_Rev_E.brd, A20-SOM-EVB_Rev_E.sch, A20-SOM-EVB_Rev_F.brd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]
2022-06-23 Update
    Revision E files
    [AM3352-SOM-EVB_Rev_D.brd, AM3352-SOM-EVB_Rev_D.sch, AM3352-SOM-EVB_Rev_E.brd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]

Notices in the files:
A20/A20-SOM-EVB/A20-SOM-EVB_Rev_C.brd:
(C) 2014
